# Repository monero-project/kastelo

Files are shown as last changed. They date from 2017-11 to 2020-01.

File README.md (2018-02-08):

# Kastelo
This is the project to create an official Monero Hardware Wallet

[Kastelo logo](https://github.com/monero-project/kastelo/)

1. [Safe, Vault](https://en.wikipedia.org/wiki/Esperanto), a place to store valuables
2. An open hardware Monero wallet

## Are you a tester looking for FW?
Please go to firmware/monezor and read the README there

## Disclaimers
- No hardware available
- Currently in the design and pre-fabrication stage

## Documentation
- Project documentation is being written
- [Moneropedia](https://getmonero.org/knowledge-base/moneropedia/) is recommended for a general introduction to the Monero-verse

## Developers
- Contributing advice is found in CONTRIBUTING.md (please review before submitting a pull request)

### Project Management
Follow the engineering pace of our project at:

[https://taiga.getmonero.org/project/michael-rfc-hwallet-1-implementation/](https://taiga.getmonero.org/project/michael-rfc-hwallet-1-implementation/)

## Support
- IRC: [Freenode](irc://chat.freenode.net/#monero-hardware/)
- [Monero StackExchange](https://monero.stackexchange.com/)
- [Mattermost](https://mattermost.getmonero.org/monero/channels/monerohardware/)

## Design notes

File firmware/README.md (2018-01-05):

# README

## About This Repository

This is a basic firmware project for the Monero HW wallet (JULIAN CANDY EDITION) intended to support firmware development. HW information for the JULIAN CANDY device is in the hardware/monezor folder.

It was established by forking and putting together files from three github repositories:

* libopencm3
* libopencm3-examples
* trezor_mcu

The goal of this blank project is to give other developers a clean start for writing cryptographic functions, or for any kind of playing with JULIAN CANDY device. All kinds of activity is welcome, there is a lot of work to be done!

Note that most of the following instruction assumes a Unix, Linux, or similar OS.

## How To Start?

### Compiling

You have to install the arm cross compiling toolchain, since this is used for compiling the code. This can be done (on debian) by running:

```
$ sudo apt-get install gcc-arm-none-eabi
```

Once this is done, there are two separate things to build: the libopencm3 library and the firmware itself. So at first, go to the libopencm3 folder and build the library by running "make". Then, change directory to to the monezor folder.
Run "make" here as well. This should result in the files named monezor.bin and monezor.elf. Once they are there, you can continue with uploading the binary :)

### USB Vendor and Product ID (user flash boot only)

We have applied for the following VID/PID assignments:

* Bootloader circuits 0x1209/0xB0B0
* Consumer editions 0x1209/0xC0DA
* Developer editions 0x1209/0xD00D
* Microchip editions 0x04D8/0x????

We are provisionally using the FOSS VID/PID values:

* Bootloader circuits 0xF055/0xB0B0
* Consumer editions 0xF055/0xC0DA
* Developer editions 0xF055/0xD00D

We have no plans to purchase our own vendor identifer from usb.org.

### USB Rules

Go to the UDEV rules folder:

```
$ cd /etc/udev/rules.d/
```

Make a new file here:

```
$ sudo nano 99-usbdfu.rules
```

Paste these lines in:

```
# STMicroelectronics STM Device in DFU Mode (and clones)
SUBSYSTEM=="usb", ATTR{idVendor}=="0483", ATTR{idProduct}=="df11", MODE="660", GROUP="plugdev"
SUBSYSTEM=="usb", ATTR{idVendor}=="f055", ATTR{idProduct}=="b0b0", MODE="660", GROUP="plugdev"
SUBSYSTEM=="usb", ATTR{idVendor}=="f055", ATTR{idProduct}=="c0da", MODE="660", GROUP="plugdev"
SUBSYSTEM=="usb", ATTR{idVendor}=="f055", ATTR{idProduct}=="d00d", MODE="660", GROUP="plugdev"
SUBSYSTEM=="usb", ATTR{idVendor}=="1209", ATTR{idProduct}=="b0b0", MODE="660", GROUP="plugdev"
SUBSYSTEM=="usb", ATTR{idVendor}=="1209", ATTR{idProduct}=="c0da", MODE="660", GROUP="plugdev"
SUBSYSTEM=="usb", ATTR{idVendor}=="1209", ATTR{idProduct}=="d00d", MODE="660", GROUP="plugdev"
```

And restart your computer (or try to restart rules by this command):

```
$ sudo udevadm control --reload-rules
$ sudo udevadm trigger --action=change
```

If you later hit some problems with uploading, please check if you have rules recognized.

### Uploading the Binary to the Device

Basically you need couple of things, depending how you want to upload the binary to the device's MCU.

If you choose to upload the binary with a USB cable, it is convenient, but you cannot do stepwise debugging or use breakpoints in code. For more granular (stepwise and breakpoint) debugging, you need to use a dedicated programmer and connect it to the JTAG port of the device (please see PDF schematics in the hardware/monezor/schematics folder) in question.

#### Uploading by USB

For flashing firmware over the USB cable, we are using ST Microelectronic's factory internal bootloader\*. This may not yield a secure boot procedure, but is quite appropriate for the rapid prototyping we're currently working on. Using this bootloader is just fine for now, since it allows to upload and test binaries without a special programmer device.

\* This bootloader cannot be deleted and we are using it because of it allows convenient uploading of binaries, even for those not owning a special programmer.

For carrying out the prescribed upload procedure, install dfu-util (this is a tool for uploading binaries over USB to devices supporting usb-dfu bootloading.)

```
$ sudo apt-get install dfu-util
```

1. Unplug your device
2. There are two jumpers on the board, just next to display. Each of them could be either in the left position (between pins 1 & 2), or the right position (between pins 2 & 3). These jumpers determine in which mode the MCU is bootloading. Put both jumper to the right positions.
3. Connect the device (you should see in dmesg, that you connected STM DFU device, which is what we need, since we are going to flash our binary by using the STM DFU on-chip bootloader.)

Now go to the firmware/monezor folder and type `make program`.
Note: if you unplug and plug in the device now, it will again boot into bootloader mode with the display turned off. So, to see the device working you have to unplug it, move the left jumper to the left position causing the MCU to boot into the binary which we just uploaded, and plug the device in again.

#### Upload by ST-LINK programmer

For flashing the firmware using a ST-LINK programmer, you have to install openocd as well:

http://openocd.org/

Be sure to provide voltage to the board before plugging in the programmer. Connect the programmer to the JTAG port, go to the firmware/monezor folder and type `make flash`.

Note: If the ST-LINK programmer is not plugged into a power supply, it holds the reset pin on the GND by default, leading to a false impression that the MCU seems to be dead :)

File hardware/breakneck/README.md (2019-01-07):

# Hardware Breakneck Design

The Breakneck design includes rich features typical of a developer edition hardware wallet.

[Breakneck schematic print](https://github.com/monero-project/kastelo/raw/master/hardware/breakneck/schematic/breakneck-sch.pdf)

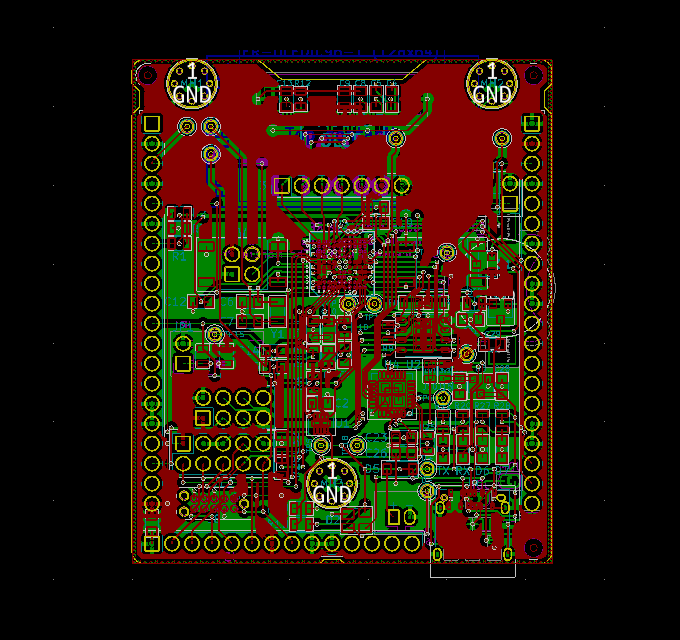
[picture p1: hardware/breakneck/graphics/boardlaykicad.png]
Breakneck CAD layout
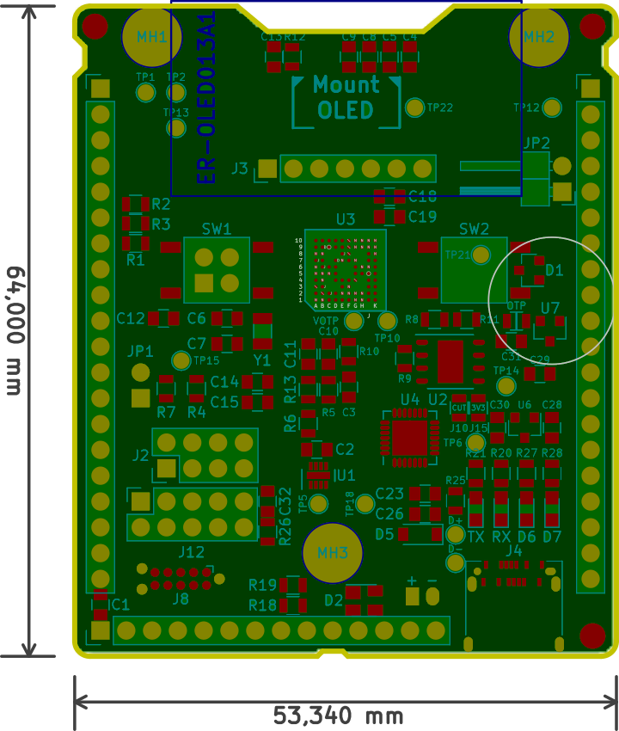
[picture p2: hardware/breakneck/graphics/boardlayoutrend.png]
Breakneck board layout
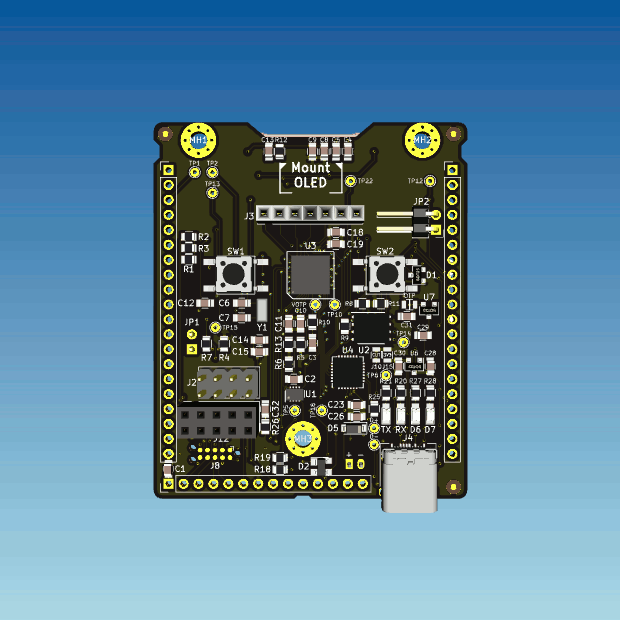
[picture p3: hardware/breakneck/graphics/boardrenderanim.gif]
Breakneck shaded animation
[](https://raw.githubusercontent.com/monero-project/kastelo/master/hardware/breakneck/graphics/boardlaykicad.png)&nbsp;&nbsp;[](https://raw.githubusercontent.com/monero-project/kastelo/master/hardware/breakneck/graphics/boardlayoutrend.png)&nbsp;&nbsp;[](https://raw.githubusercontent.com/monero-project/kastelo/master/hardware/breakneck/graphics/boardrenderanim.gif)

## Getting Started

The Breakneck design consists of several files, some which are not tracked in revision control but are part of [project releases](https://github.com/monero-project/kastelo/releases/).

* breakneck.pro (KiCad project)
* breakneck.sch (KiCad schematic)
* breakneck.kicad_pcb (KiCad layout)
* libraries (KiCad libraries)
* modules (KiCad footprints)

Fabrication subdirectories contain files meant for printing, assembly, and other production work.

* billofmat (Bill of materials generated from the layout)
* fabpanel (Gerber files for printing panelized PCBs)
* fabraster (3D rendition of a single PCB layout)
* fabsingle (Gerber files for printing single PCBs)
* fabvector (Vector files useful for mechanical engineering)

Other subdirectories exist to provide conveniently formatted files generated from source.

* release (Tested distribution release files containing change logs)
* schematic (Copy of breakneck.sch converted to common graphic formats)

A Makefile serves project management tasks allowing for scripting and automation.

* Makefile (A GNU Makefile facilitating command line project tasks)

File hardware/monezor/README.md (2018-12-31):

## Monezor Design Status

This was the monezor hw wallet PCB revision control.

New development of STM32 based designs throughout the project stopped after the Julian Candy released hardware revision 0.2.0.

## Exit Reasoning

STM32 integration stopped as the architecture (at least M3 based MCUs) failed to meet expectations, as well as better architectures with immutable boot and hardware cryptography appeared.

## Maintenance Plan

STM32 design is maintained in the (developer edition) Breakneck codebase, for those who prefer the architecture opposed to the advanced and improved one found in the tip master of revision control.

To find the STM32 based Breakneck codebase, switch to the _revstm_ branch:

```
$ git checkout revstm
$ cd hardware/breakneck
```

## Development Plan

New features are found in the Breakneck master codebase which migrates logic to a new consumer edition codebase as UX and functional testing mandates.

To find the current Breakneck codebase, switch to the _master_ branch:

```
$ git checkout master
$ cd hardware/breakneck
```

## New Architecture

Although nRF52840 is a candidate, the replacement for STM32 parts in new designs is CEC1702.

## Preservation Plan

The STM32 based Monezor codebase is preserved in the _revstm_ branch.

## Glossary

- **Consumer edition:** One of two Monero dedicated hardware wallet editions, integrating a well tested subset of features from the developer edition.
- **Developer edition:** One of two Monero dedicated hardware wallet editions, including all features. For example, the developer edition may contain experimental intrusion detection while the consumer edition may not (unless the features are proven stable and useful.)
- **Monezor:** The model name associated with the consumer edition.
- **Breakneck:** The model name associated with the developer edition.
- **Julian Candy:** A code name corresponding with a range of hardware revisions including 0.2.0.
- **Extra Tabulo:** A code name corresponding with a range of hardware revisions including 0.9.0.

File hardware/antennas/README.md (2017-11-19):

# Hardware Antennas Subdirectory

One paragraph of descriptive text.

## Getting Started

Example text to help understand contents and subdirectories.

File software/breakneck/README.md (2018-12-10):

# Host Software for Breakneck

This area serves software projects for the Breakneck and similar device models. Deliverables run on consumer grade desktop computers and mobile devices. For MCU bound firmware, please navigate to the corresponding parent directory.

## Getting Started

Example text to help understand contents and subdirectories.

---

## Development Platforms

To provide quality sofware while reducing maintenance, abstraction frameworks are used:

* [Electron](https://https://electronjs.org/)
* [React Native](https://facebook.github.io/react-native/)

Electron is used to produce binaries for desktop hosts whereas React Native is used to produce binaries for mobile hosts. A console application serves text based use requirements.

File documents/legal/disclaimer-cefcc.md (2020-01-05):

# CE and FCC mark exception notice

## Evaluation Products not Requiring FCC Equipment Authorisation (FCC Rule 2.803)

FCC NOTICE: This kit is designed to allow:
(1) Product developers to evaluate electronic components, circuitry, or software associated with the kit to determine whether to incorporate such items in a finished product and
(2) Software developers to write software applications for use with the end product. This kit is not a finished product and when assembled may not be resold or otherwise marketed unless all required FCC equipment authorisations are first obtained. Operation is subject to the condition that this product not cause harmful interference to licensed radio stations and that this product accept harmful interference. Unless the assembled kit is designed to operate under part 15, part 18 or part 95 of 47 CFR, Chapter I ("FCC Rules"), the operator of the kit must operate under the authority of an FCC license holder or must secure an experimental authorisation under part 5 of this chapter.

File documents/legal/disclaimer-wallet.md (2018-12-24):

# RFC-HWALLET-1 DEVELOPER EDITION DISCLAIMER 20181200

## 1. STATUS

RFC-HWALLET-1 development team (“HWDT”) is a loose collective of individuals with an aim of developing an Open Source printed circuit board design for a dedicated Monero hardware wallet. There is no centralized authority, entity, or institution that controls, dictates, regulates, or makes decisions for, or on behalf of, any member of the collective. It is not the intent of HWDT to form any partnership, joint venture, agency, employer-employee or fiduciary relationship.

## 2. DELIVERY

HWDT delivers a Development Package (“DP”) that includes evaluation boards, components, and/or documentation to developers (“Users”), who are qualified technicians familiar with handling electrical and mechanical components. Users voluntarily and knowingly assume the risks associated with handling such components, which could potentially lead to shock, fire, serious injury, and/or damage to property. Users undertake to take all necessary measures to minimize these risks. The DP is an unfinished product intended to be used for experimentation in a controlled research and development setting. The DP may not be sold for consumer or commercial use.

## 3. DISCLAIMER

The DP is provided “as is” and any express or implied warranties, including, but not limited to, implied warranties of merchantability, of satisfactory quality, non-infringement of third party rights, and fitness for a particular purpose or use are disclaimed. HWDT makes no representation that DP, does or will not infringe any patent, copyright, trade secret or other proprietary right. Users warrant that they do not act in a consumer capacity.

## 4. LIMITATION OF LIABILITY

HWDT shall have no liability, neither jointly nor severally, for direct, indirect, special, incidental, consequential, exemplary, punitive or other damages of any character including, without limitation, procurement of substitute goods or services, loss of use, data or profits, or business interruption, however caused and on any theory of contract, warranty, tort (including negligence), product liability or otherwise, arising in any way in relation to the DP. Users shall hold HWDT free and harmless from any and all liability, costs, damages, fees and expenses, including claims by third parties.

## 5. SANCTIONS

Users acknowledge that the DP may include technology subject to sanctions, embargoes, or export control regulations and shall undertake to ensure compliance with any applicable laws.

## 6. CUSTOMS

The DP is intended to be used exclusively for testing to find out components’ composition, quality or other characteristics for information, or for industrial or commercial research. Users may be able to import DP free from duty, excise duty and VAT in some countries, but should consult with the appropriate local authorities on how to obtain relief. Normally, Users must completely use up or destroy goods in the course of the testing to qualify for relief.

## 7. EVALUATION TOKENS

Some devices may include evaluation tokens. These tokens exist in a test network (“testnet”), which is separate from the main Monero network and subject to network resets at any time. As such, said tokens do not contain any value. Testnet addresses are identified by an address prefix that start with A, B, or 9.

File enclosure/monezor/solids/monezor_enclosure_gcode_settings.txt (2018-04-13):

;   processName,Medium Res 0.17 
;   applyToModels,monezor_enclosure
;   profileName,Default (modified)
;   profileVersion,2015-05-01 08:00:00
;   baseProfile,
;   printMaterial,
;   printQuality,
;   printExtruders,
;   extruderName,Extruder 1
;   extruderToolheadNumber,0
;   extruderDiameter,0.4
;   extruderAutoWidth,1
;   extruderWidth,0.48
;   extrusionMultiplier,1
;   extruderUseRetract,1
;   extruderRetractionDistance,0.5
;   extruderExtraRestartDistance,0
;   extruderRetractionZLift,0
;   extruderRetractionSpeed,2400
;   extruderUseCoasting,1
;   extruderCoastingDistance,0.2
;   extruderUseWipe,1
;   extruderWipeDistance,2
;   primaryExtruder,0
;   layerHeight,0.17
;   topSolidLayers,6
;   bottomSolidLayers,4
;   perimeterOutlines,2
;   printPerimetersInsideOut,1
;   startPointOption,3
;   startPointOriginX,200
;   startPointOriginY,0
;   sequentialIslands,0
;   spiralVaseMode,0
;   firstLayerHeightPercentage,150
;   firstLayerWidthPercentage,100
;   firstLayerUnderspeed,0.5
;   useRaft,1
;   raftExtruder,0
;   raftTopLayers,3
;   raftBaseLayers,2
;   raftOffset,2
;   raftSeparationDistance,0.18
;   raftTopInfill,100
;   aboveRaftSpeedMultiplier,0.3
;   useSkirt,0
;   skirtExtruder,0
;   skirtLayers,1
;   skirtOutlines,1
;   skirtOffset,1
;   usePrimePillar,0
;   primePillarExtruder,999
;   primePillarWidth,12
;   primePillarLocation,7
;   primePillarSpeedMultiplier,1
;   useOozeShield,0
;   oozeShieldExtruder,999
;   oozeShieldOffset,2
;   oozeShieldOutlines,1
;   oozeShieldSidewallShape,1
;   oozeShieldSidewallAngle,30
;   oozeShieldSpeedMultiplier,1
;   infillExtruder,0
;   internalInfillPattern,Rectilinear
;   externalInfillPattern,Rectilinear
;   infillPercentage,10
;   outlineOverlapPercentage,15
;   infillExtrusionWidthPercentage,125
;   minInfillLength,5
;   infillLayerInterval,1
;   internalInfillAngles,45,-45
;   overlapInternalInfillAngles,0
;   externalInfillAngles,45,-45
;   generateSupport,1
;   supportExtruder,0
;   supportInfillPercentage,30
;   supportExtraInflation,0
;   supportBaseLayers,0
;   denseSupportExtruder,0
;   denseSupportLayers,0
;   denseSupportInfillPercentage,70
;   supportLayerInterval,1
;   supportHorizontalPartOffset,1
;   supportUpperSeparationLayers,2
;   supportLowerSeparationLayers,2
;   supportType,0
;   supportGridSpacing,4
;   maxOverhangAngle,60
;   supportAngles,0
;   temperatureName,Extruder 1 Temperature,Heated Bed
;   temperatureNumber,0,0
;   temperatureSetpointCount,1,1
;   temperatureSetpointLayers,1,1
;   temperatureSetpointTemperatures,200,60
;   temperatureStabilizeAtStartup,1,1
;   temperatureHeatedBed,0,1
;   temperatureRelayBetweenLayers,0,0
;   temperatureRelayBetweenLoops,0,0
;   fanLayers,1,2,3,5
;   fanSpeeds,0,20,40,80
;   blipFanToFullPower,1
;   adjustSpeedForCooling,1
;   minSpeedLayerTime,5
;   minCoolingSpeedSlowdown,20
;   increaseFanForCooling,0
;   minFanLayerTime,45
;   maxCoolingFanSpeed,100
;   increaseFanForBridging,0
;   bridgingFanSpeed,100
;   use5D,1
;   relativeEdistances,0
;   allowEaxisZeroing,1
;   independentExtruderAxes,0
;   includeM10123,0
;   stickySupport,1
;   applyToolheadOffsets,0
;   gcodeXoffset,0
;   gcodeYoffset,0
;   gcodeZoffset,0
;   overrideMachineDefinition,0
;   machineTypeOverride,0
;   strokeXoverride,200
;   strokeYoverride,200
;   strokeZoverride,200
;   originOffsetXoverride,0
;   originOffsetYoverride,0
;   originOffsetZoverride,0
;   homeXdirOverride,-1
;   homeYdirOverride,-1
;   homeZdirOverride,-1
;   flipXoverride,1
;   flipYoverride,-1
;   flipZoverride,1
;   toolheadOffsets,0,0|0,0|0,0|0,0|0,0|0,0
;   overrideFirmwareConfiguration,0
;   firmwareTypeOverride,RepRap (Marlin/Repetier/Sprinter)
;   GPXconfigOverride,r2
;   baudRateOverride,115200
;   overridePrinterModels,0
;   printerModelsOverride
;   startingGcode,;M190 S{print_bed_temperature} 	;Uncomment to add your own bed temperature line,;M109 S{print_temperature} 		;Uncomment to add your own temperature line,G21       			;metric values,G90      			;absolute positioning,M82      			;set extruder to absolute mode,M107      			;start with the fan off,G28 X0 Y0 			;move X/Y to min endstops,G28 Z0     			;move Z to min endstops,G1 Z5.0 F1500			;move the platform down 15mm,G1 Z0			;move extruder to 0,G92 E0                		;zero the extruded length,G1 F900 E20              		;extrude 10mm of feed stock,G92 E0                 		;zero the extruded length again,G1 F{travel_speed},M117 Leave me alone!... 		;Put printing message on LCD screen
;   layerChangeGcode,
;   retractionGcode,
;   toolChangeGcode,
;   endingGcode,;End GCode,M104 S0 		;extruder heater off,M140 S0 		;heated bed heater off (if you have it),M107     		;disable fans,G91       		;relative positioning,G1 E-10 F900		;retract the filament a bit before lifting the nozzle to release some of the pressure,G1 Z+2 E-10 X-20 Y-20 F1500	;move Z up a bit and retract filament even more,G1 X0 Y200  F1500	;move bed to front,M84		;steppers off,G90		;absolute positioning,;{profile_string},M117 Hooooray!!!...	;Put printing message on LCD screen
;   exportFileFormat,gcode
;   celebration,0
;   celebrationSong,Star Wars
;   postProcessing,
;   defaultSpeed,2400
;   outlineUnderspeed,0.75
;   solidInfillUnderspeed,1
;   supportUnderspeed,1
;   rapidXYspeed,9000
;   rapidZspeed,1002
;   minBridgingArea,10
;   bridgingExtraInflation,0
;   bridgingExtrusionMultiplier,0.9
;   bridgingSpeedMultiplier,1
;   useFixedBridgingAngle,0
;   fixedBridgingAngle,0
;   applyBridgingToPerimeters,0
;   filamentDiameters,1.75|1.75|1.75|1.75|1.75|1.75
;   filamentPricesPerKg,36|36|36|36|36|36
;   filamentDensities,1.25|1.25|1.25|1.25|1.25|1.25
;   useMinPrintHeight,0
;   minPrintHeight,0
;   useMaxPrintHeight,0
;   maxPrintHeight,0
;   useDiaphragm,0
;   diaphragmLayerInterval,20
;   robustSlicing,1
;   mergeAllIntoSolid,0
;   onlyRetractWhenCrossingOutline,0
;   retractBetweenLayers,1
;   useRetractionMinTravel,0
;   retractionMinTravel,3
;   retractWhileWiping,0
;   onlyWipeOutlines,1
;   avoidCrossingOutline,0
;   maxMovementDetourFactor,3
;   toolChangeRetractionDistance,0
;   toolChangeExtraRestartDistance,0
;   toolChangeRetractionSpeed,360
;   externalThinWallType,0
;   internalThinWallType,2
;   thinWallAllowedOverlapPercentage,10
;   singleExtrusionMinLength,1
;   singleExtrusionMinPrintingWidthPercentage,50
;   singleExtrusionMaxPrintingWidthPercentage,200
;   singleExtrusionEndpointExtension,0.2
;   horizontalSizeCompensation,0

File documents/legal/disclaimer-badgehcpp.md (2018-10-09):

# HCPP 18 BADGE DISCLAIMER 20180900

## 1. STATUS

The Monero Hardware Team (“MHT”) is a loose collective of individuals that aim to provide hardware at HCPP 18. There is no centralized authority, entity, or institution that controls, dictates, regulates, or makes decisions for, or on behalf of, any member of the collective. It is not the intent of MHT to form any partnership, joint venture, agency, employer-employee or fiduciary relationship.

## 2. DELIVERY

MHT delivers a HCPP 18 Badge (“BADGE”) that is constructed of open electrical components to Users on condition that Users voluntarily and knowingly assume the risks associated with handling such components, which could potentially lead to shock, fire, serious injury, and/or damage to property. Users undertake to take all necessary measures to minimize these risks. The BADGE is an unfinished product to be used for experimentation and does not have any specific intended use case.

## 3. DISCLAIMER

The BADGE is provided “AS IS” and any express or implied warranties, including, but not limited to, implied warranties of merchantability, of satisfactory quality, non-infringement of third party rights, and fitness for a particular purpose or use are disclaimed. MHT makes no representation that BADGE does or will not infringe any patent, copyright, trade secret or other proprietary right.

## 4. LIMITATION OF LIABILITY

MHT shall have no liability, neither jointly nor severally, for direct, indirect, special, incidental, consequential, exemplary, punitive or other damages of any character including, without limitation, procurement of substitute goods or services, loss of use, data or profits, or business interruption, however caused and on any theory of contract, warranty, tort (including negligence), product liability or otherwise, arising in any way in relation to the BADGE. Users shall hold MHT free and harmless from any and all liability, costs, damages, fees and expenses, including claims by third parties.

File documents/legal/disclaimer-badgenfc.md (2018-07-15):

# MONERO DEFCON 26 BADGE DISCLAIMER 20180700

## 1. STATUS

The Monero Village (“MV”) is a loose collective of individuals that aim to represent the Monero Project at DefCon 26. There is no centralized authority, entity, or institution that controls, dictates, regulates, or makes decisions for, or on behalf of, any member of the collective. It is not the intent of MV to form any partnership, joint venture, agency, employer-employee or fiduciary relationship.

## 2. DELIVERY

MV delivers a Monero DefCon Badge (“BADGE”) that is constructed of open electrical components to Users on condition that Users voluntarily and knowingly assume the risks associated with handling such components, which could potentially lead to shock, fire, serious injury, and/or damage to property. Users undertake to take all necessary measures to minimize these risks. The BADGE is an unfinished product to be used for experimentation and does not have any specific intended use case.

## 3. DISCLAIMER

The BADGE is provided “AS IS” and any express or implied warranties, including, but not limited to, implied warranties of merchantability, of satisfactory quality, non-infringement of third party rights, and fitness for a particular purpose or use are disclaimed. MV makes no representation that BADGE does or will not infringe any patent, copyright, trade secret or other proprietary right.

## 4. LIMITATION OF LIABILITY

MV shall have no liability, neither jointly nor severally, for direct, indirect, special, incidental, consequential, exemplary, punitive or other damages of any character including, without limitation, procurement of substitute goods or services, loss of use, data or profits, or business interruption, however caused and on any theory of contract, warranty, tort (including negligence), product liability or otherwise, arising in any way in relation to the BADGE. Users shall hold MV free and harmless from any and all liability, costs, damages, fees and expenses, including claims by third parties.

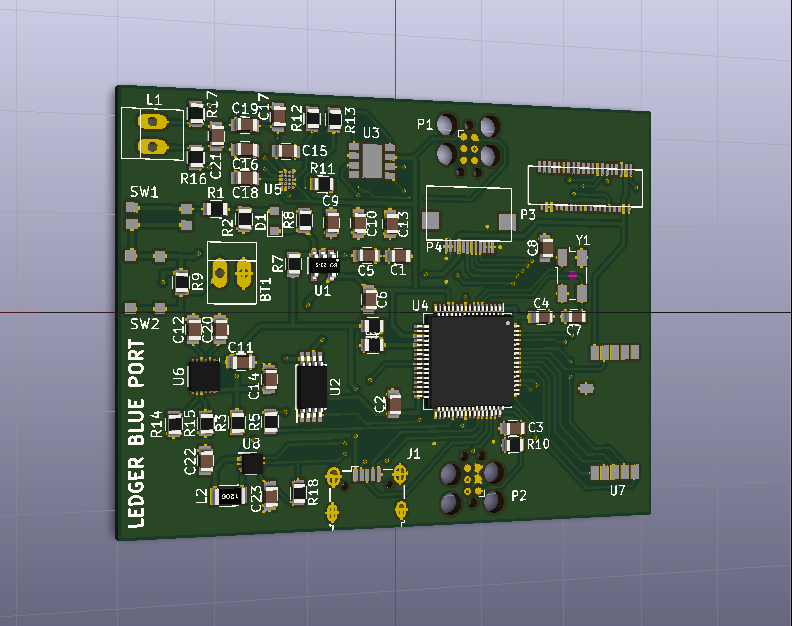
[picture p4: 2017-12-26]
hardware/cloneledg/ledgblue/fabraster/ledgbluerendition.png

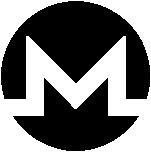
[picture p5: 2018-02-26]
hardware/breakneck/graphics/monerochromcopper.png

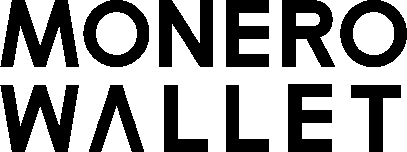
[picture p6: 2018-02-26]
hardware/breakneck/graphics/monerochromtext.png

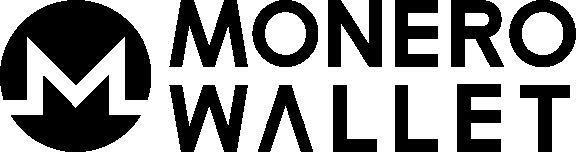
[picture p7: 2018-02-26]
hardware/breakneck/graphics/monerofullchrome.png

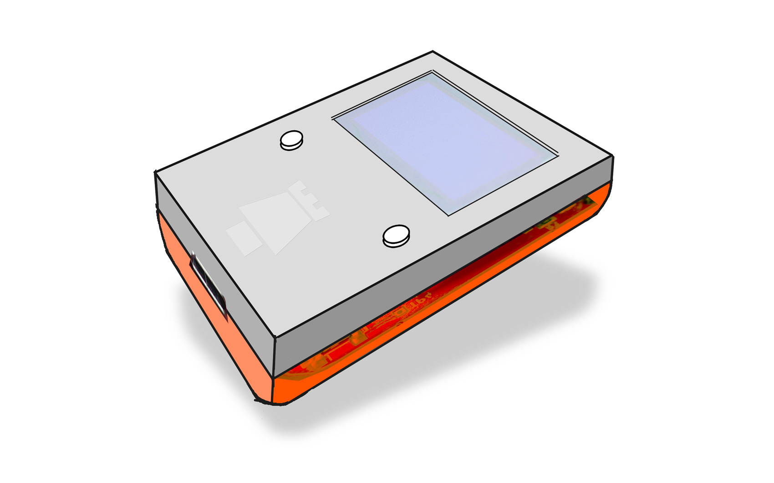
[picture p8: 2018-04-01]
enclosure/monezor/concepts/lowprotwopiece.jpeg

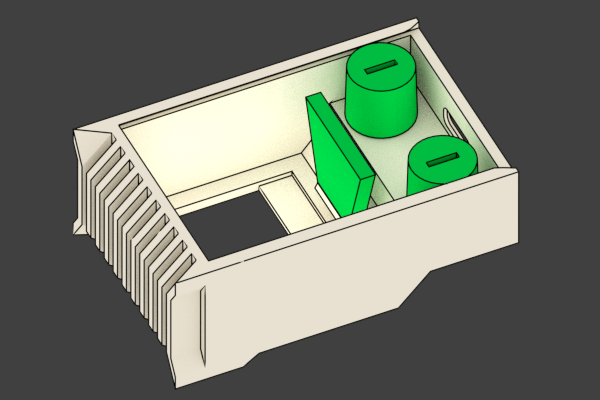
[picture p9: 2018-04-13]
enclosure/monezor/solids/monezor_enclosure_support.png

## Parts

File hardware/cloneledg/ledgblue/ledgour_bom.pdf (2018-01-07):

Ledgour BoM Updated 2018-01-07

Name | Package | Designation | Qty | Link | Alternative link
C1,C2,C3,C4,C9,C13 | C_0805 | 0.1uF | 6 | https //www.arrow.com/en/products/vj0805y104jxxcw1bc/vishay
C5,C6,C22,C23 | C_0805 | 1uF | 4 | https //www.arrow.com/en/products/vj0805y105jxqtw1bc/vishay
C7,C8 | C_0805 | 20pF | 2 | https //www.arrow.com/en/products/nmc0805npo200j50trpf/nic-components
C10,C14 | C_0805 | 4.7uF | 2 | https //www.arrow.com/en/products/vj0805v475zxqtw1bc/vishay
C11,C12,C20 | C_0805 | 2.2uF | 3 | https //www.arrow.com/en/products/vj0805g225kxqtw1bc/vishay
C15 | C_0805 | 0.015uF | 1 | https //www.arrow.com/en/products/cl21b153kbannnc/samsung-electro-mechanics
C16,C17 | C_0805 | 27pF | 2 | https //www.arrow.com/en/products/cl21c270jbannnc/samsung-electro-mechanics
C18,C19 | C_0805 | 180pF | 2 | https //www.arrow.com/en/products/cl21c181jbannnd/samsung-electro-mechanics
C21 | C_0805 | 39pF | 1 | https //www.arrow.com/en/products/cl21c390jbannnc/samsung-electro-mechanics
R1,R2,R14 | R_0805 | 10k | 3 | https //www.arrow.com/en/products/crcw080510k0jnea/vishay
R3,R4,R5,R6 | R_0805 | 1.2k | 4 | https //www.arrow.com/en/products/crcw08051k20fkea/vishay
R7 | R_0805 | 680k | 1 | https //www.arrow.com/en/products/crcw0805680kfkea/vishay
R8 | R_0805 | 1M | 1 | https //www.arrow.com/en/products/crcw08051m00jneahp/vishay
R9,R12,R13,R16,R17 | R_0805 | 0 | 5 | https //www.arrow.com/en/products/rca08050000zsea/vishay
R10,R11 | R_0805 | 100k | 2 | https //www.arrow.com/en/products/crcw0805100kfkeb/vishay
R15 | R_0805 | 1k | 1 | https //www.arrow.com/en/products/crcw08051k00jnta/vishay
R18 | R_0805 | 10 | 1 | https //www.arrow.com/en/products/crcw080510r0jnea/vishay
BT1 | PINHEAD1-2 | Battery | 1 | https //www.arrow.com/en/products/0901200778/molex
L1 | PINHEAD1-2 | Antenna | 1 | https //www.arrow.com/en/products/0901200778/molex
L2 | L_1206 | 10uH | 1 | https //www.arrow.com/en/products/nlcv32t-100k-pfr/tdk
D1 | D_0805 | D_Schottky | 1 | https //www.arrow.com/en/products/sd0805s020s0r5/avx
SW1 | wurth436353045816 | WURTH 436353045816 1 | http //uk.farnell.com/wurth-elektronik/436353045816/switch-160gf-side-wte-j-bend-boss/dp/1868021 | https //www.digikey.com/product-detail/en/wurth-electronics-inc/436353045816/732-7062-1-ND/5225510
SW2 | multicompMCFTE-3C-V | SW-PB | 1 | http //uk.farnell.com/multicomp/mcfte-3c-v/switch-micro-detect-smd/dp/1316985
U1 | SOT-23-5 | LD39020 | 1 | https //www.arrow.com/en/products/ld39020adm30r/stmicroelectronics
U2 | TSSOP-8_4.4x3mm_Pitch0.65mm STMPS2151TTR | 1 | https //www.arrow.com/en/products/stmps2151ttr/stmicroelectronics | https //www.mouser.de/ProductDetail/STMicroelectronics/STMPS2151TTR/?qs qolwYojYp3TtdEE8TCWfkg
U3 | WLCSP | ST31G480 | 1 | N/A to due NDA
U4 | LQFP-64_10x10mm_P tch0.5mm | STM32L476RCT6 | 1 | https //www.arrow.com/en/products/stm32l476rct6/stmicroelectronics
U5 | amsAS3921 | AMS_AS3921 | 1 | https //www.arrow.com/en/products/as3921-bwlt/ams-ag | https //www.mouser.de/ProductDetail/ams/AS3921-BWLM/?qs 16w8nSHsg3vn3%252bCT5rH3bA
U6 | DFN-12-1EP_3x3mm_Pitch0.45mm STNS01PUR | 1 | https //www.arrow.com/en/products/stns01pur/stmicroelectronics
U7 | STSPBTLE-RF | SPBTLE-RF | 1 | https //www.arrow.com/en/products/spbtle-rf/stmicroelectronics | https //www.mouser.de/ProductDetail/STMicroelectronics/SPBTLE-RF0/?qs Mv7BduZupUjx1Mbf4ryoAA%3d%3d
U8 | DFN-6-1EP_2x2mm_Pitch0.5mm | STLA02PUR | 1 | https //www.arrow.com/en/products/stla02pur/stmicroelectronics | https //www.mouser.de/ProductDetail/STMicroelectronics/STLA02PUR/?qs L6eUzyzWLAtrJwKaBBv23Q
Y1 | 4pin_5.0x3.2mm | Abracon_ABM3B_8MHz 1 | https //www.arrow.com/en/products/abm3b-8.000mhz-b2-t/abracon
P1,P2 | Tag Connect TC2030-IDC | Tag Connect TC2030-IDC 2 | http //www.tag-connect.com/TC2030-IDC
P3 | hiroseFH23-39S | YL035MY2 | 1 | https //www.mouser.de/ProductDetail/?qs 0N%252bVULUZFj%2fgb7SvV3hxJA
P4 | wurth687-112-149-022 | YL035MY2_TS_WURTH 1 | https //www.mouser.de/ProductDetail/Wurth-Electronics/687112149022/?qs a9WhcLg8qCybEd8lzi%2fupw
J1 | USB_Micro-B | Wuerth-629105150521 | 1 | https //www.mouser.de/productdetail/wurth-electronics/629105150521?qs sGAEp MZZMulM8LPOQ%252byk2Wnkghg7F8rzYbeZ9K0ijhE7azhp8rv2w

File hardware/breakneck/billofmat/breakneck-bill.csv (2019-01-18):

ID | Reference | Footprint | Quantity | Value | Manufacturer | Datasheet
1 | BT1 | Keystone_3000_1x12mm-CoinCell | 1 | Battery_Cell | Keystone Electronics Corporation | https://www.keyelco.com/product.cfm/product_id/777/
2 | C1,C2,C8,C11,C15,C17,C19,C21,C22,C23,C25,C26 | C_0805 | 12 | 100nF | Yageo Corporation | http://www.yageo.com/documents/recent/UPY-GPHC_Y5V_6.3V-to-50V_8.pdf
3 | C3,C14 | C_0805 | 2 | 470nF | Yageo Corporation | http://www.yageo.com/documents/recent/UPY-GPHC_Y5V_6.3V-to-50V_8.pdf
4 | C4,C5,C9,C10,C12,C16,C18,C28,C29,C30,C31,C32 | C_0805 | 12 | 1uF | Yageo Corporation | http://www.yageo.com/documents/recent/UPY-GPHC_Y5V_6.3V-to-50V_8.pdf
5 | C6,C7 | C_0805 | 2 | 15pF | Yageo Corporation | http://www.yageo.com/documents/recent/UPY-GPHC_Y5V_6.3V-to-50V_8.pdf
6 | C13,C20,C24,C27 | C_0805 | 4 | 2.2uF | Yageo Corporation | http://www.yageo.com/documents/recent/UPY-GPHC_Y5V_6.3V-to-50V_8.pdf
7 | D1 | SOT-23 | 1 | BAT54C | Vishay Intertechnology, Incorporated | http://www.vishay.com/docs/85508/bat54.pdf
8 | D2 | SOT-143 | 1 | SP0503BAHTG | Littelfuse Incorporated | http://www.littelfuse.com/~/media/files/littelfuse/technical%20resources/documents/data%20sheets/sp05xxba.pdf
9 | D3,D4,D6,D7 | LED_0805 | 4 | LED | Osram Opto Semiconductors Incorporated | https://dammedia.osram.info/media/resource/hires/osram-dam-2493936/LG%20R971.pdf
10 | D5 | D_SOD-123 | 1 | D_PMEG | Nexperia B.V. | https://assets.nexperia.com/documents/data-sheet/PMEG3010EGW.pdf
11 | DS1 | Eastrising_ER-CON30HT-1_01x30_P0.50mm | 1 | ER-CON30 | EastRising Technology Corporation, Limited | https://www.buydisplay.com/download/connector/ER-CON30HT-1.pdf
12 | DS2 | Eastrising_ER-CON24HT-1_01x24_P0.50mm | 1 | ER-CON24 | EastRising Technology Corporation, Limited | https://www.buydisplay.com/download/connector/ER-CON24HT-1.pdf
13 | J1 | Pin_Header_Straight_1x20_Pitch2.54mm | 1 | CONN_WEST | Sullins Connector Solutions | https://suddendocs.samtec.com/catalog_english/tsw_th.pdf
14 | J2 | Pin_Header_Straight_2x04_Pitch2.54mm | 1 | CONN_DEDI | Sullins Connector Solutions | https://suddendocs.samtec.com/catalog_english/tsw_th.pdf
15 | J3 | Socket_Strip_Straight_1x07_Pitch2.54mm | 1 | CONN_OLED | Sullins Connector Solutions | http://www.sullinscorp.com/product/?pn=PPTC071LFBN-RC
16 | J4 | USB_C_Receptacle_Amphenol_12401610E4-2A | 1 | USB_C_Receptacle | Amphenol Corporation | https://cdn.amphenol-icc.com/media/wysiwyg/files/drawing/c12401610_c.pdf
16 | J5 | Pin_Header_Straight_1x14_Pitch2.54mm | 1 | CONN_SOUTH | Sullins Connector Solutions | https://suddendocs.samtec.com/catalog_english/tsw_th.pdf
18 | J6 | Pin_Header_Straight_1x20_Pitch2.54mm | 1 | CONN_EAST | Sullins Connector Solutions | https://suddendocs.samtec.com/catalog_english/tsw_th.pdf
19 | J7 | 10120045-401LF | 1 | Badgebus | Amphenol Corporation | https://cdn.amphenol-icc.com/media/wysiwyg/files/documentation/datasheet/boardwiretoboard/bwb_rotaconnect_rotatable_btb.pdf
20 | J12 | Socket_Strip_Angled_2x05_Pitch2.54mm | 1 | CONN_JTAG_6P | Samtec Incorporated | https://suddendocs.samtec.com/catalog_english/ssq_th.pdf
21 | J13 | microSD_Card_Receptacle_Hirose_DM3AT-SF-PEJM5 | 1 | Micro_SD_Card_Det | Hirose Electric Corporation, LTD | https://www.hirose.com/product/en/download_file/key_name/DM3AT-SF-PEJM5/category/Catalog/doc_file_id/49662/
22 | J16 | JST_PH_B2B-PH-K_02x2.00mm_Straight | 1 | CONN_JST | J.S.T. Manufacturing Corporation, Limited | http://www.jst-mfg.com/product/pdf/eng/ePH.pdf
23 | JP1,JP2 | Pin_Header_Angled_1x02_Pitch2.54mm | 2 | Jumper | Sullins Connector Solutions | https://suddendocs.samtec.com/catalog_english/tsw_th.pdf
24 | R1,R7 | R_0805 | 2 | 0 | Stackpole Electronics Incorporated | https://www.seielect.com/Catalog/SEI-RMCF_RMCP.pdf
25 | R2 | R_0805 | 1 | 12K | Stackpole Electronics Incorporated | https://www.seielect.com/Catalog/SEI-RMCF_RMCP.pdf
26 | R3 | R_0805 | 1 | 22K | Stackpole Electronics Incorporated | https://www.seielect.com/Catalog/SEI-RMCF_RMCP.pdf
27 | R4,R29 | R_0805 | 2 | 10K | Stackpole Electronics Incorporated | https://www.seielect.com/Catalog/SEI-RMCF_RMCP.pdf
28 | R5,R6 | R_0805 | 2 | 3.9K | Stackpole Electronics Incorporated | https://www.seielect.com/Catalog/SEI-RMCF_RMCP.pdf
29 | R8,R9,R11,R26 | R_0805 | 4 | 100K | Stackpole Electronics Incorporated | https://www.seielect.com/Catalog/SEI-RMCF_RMCP.pdf
30 | R10 | R_0805 | 1 | 10 | Stackpole Electronics Incorporated | https://www.seielect.com/Catalog/SEI-RMCF_RMCP.pdf
31 | R12,R14 | R_0805 | 2 | 390K | Stackpole Electronics Incorporated | https://www.seielect.com/Catalog/SEI-RMCF_RMCP.pdf
32 | R13 | R_0805 | 1 | 100 | Stackpole Electronics Incorporated | https://www.seielect.com/Catalog/SEI-RMCF_RMCP.pdf
33 | R15 | R_0805 | 1 | 1.5K | Stackpole Electronics Incorporated | https://www.seielect.com/Catalog/SEI-RMCF_RMCP.pdf
34 | R16,R17 | R_0805 | 2 | 2.4K | Stackpole Electronics Incorporated | https://www.seielect.com/Catalog/SEI-RMCF_RMCP.pdf
35 | R18 | R_0805 | 1 | 22.1K | Stackpole Electronics Incorporated | https://www.seielect.com/Catalog/SEI-RMCF_RMCP.pdf
36 | R19 | R_0805 | 1 | 47.5K | Stackpole Electronics Incorporated | https://www.seielect.com/Catalog/SEI-RMCF_RMCP.pdf
37 | R27,R28 | R_0805 | 2 | 150 | Stackpole Electronics Incorporated | https://www.seielect.com/Catalog/SEI-RMCF_RMCP.pdf
38 | R20,R21 | R_0805 | 2 | 220 | Stackpole Electronics Incorporated | https://www.seielect.com/Catalog/SEI-RMCF_RMCP.pdf
39 | R22,R25 | R_0805 | 2 | 1K | Stackpole Electronics Incorporated | https://www.seielect.com/Catalog/SEI-RMCF_RMCP.pdf
40 | R23 | R_0805 | 1 | 130K | Stackpole Electronics Incorporated | https://www.seielect.com/Catalog/SEI-RMCF_RMCP.pdf
41 | R24 | R_0805 | 1 | 220K | Stackpole Electronics Incorporated | https://www.seielect.com/Catalog/SEI-RMCF_RMCP.pdf
42 | SW1,SW2 | SW_SPST_K21102SP | 2 | SW_SPST | Korean Hroparts Electronics Corporation, LTD | https://datasheet.lcsc.com/szlcsc/Korean-Hroparts-Elec-K2-1102SP-C4SC-04_C127509.pdf
43 | SW3 | SW_SPST_ESE11MV1 | 1 | SW_SPST | Panasonic Electronic Components | https://industrial.panasonic.com/cdbs/www-data/pdf/ATB0000/ATB0000C14.pdf
44 | SW4 | SW_SPDT_CLSB-12A | 1 | SW_SPDT | Nidec Copal Electronics Incorporated | https://www.nidec-copal-electronics.com/e/catalog/switch/cl-sb.pdf
45 | TP1-TP22 | TestPoint_THTPad_D1.5mm_Drill0.7mm | 22 | Testpoints (various)
46 | U1 | DFN-8-1EP_2x3mm_Pitch0.5mm | 1 | ATECC508A | Atmel Corporation | http://ww1.microchip.com/downloads/en/DeviceDoc/20005927A.pdf
47 | U2 | DFN-S-8-1EP_6x5mm_Pitch1.27mm | 1 | SST26VF064B | Microchip Technology Incorporated | https://www.microchip.com/downloads/en/DeviceDoc/00002207C.pdf
48 | U3 | WFBGACEC1702 | 1 | CEC1702 | Microchip Technology Incorporated | https://www.microchip.com/downloads/en/DeviceDoc/00002207C.pdf
49 | U4 | QFN-28-1EP_5x5mm_Pitch0.5mm | 1 | CP2102N | Silicon Laboratories | https://www.silabs.com/documents/public/data-sheets/cp2102n-datasheet.pdf
50 | U5 | SOT-353_SC-70-5 | 1 | MIC5377YC5 | Microchip Technology Incorporated | https://www.microchip.com/downloads/en/DeviceDoc/MIC5376-7-8-High-Performance-Low-Dropout-150mA-LDO-DS20006080A.pdf
51 | U6 | SOT-23 | 1 | LN6206P33M | Shanghai Nanlin Electronics | http://www.natlinear.com/uploadfiles/2014/LN/LN6206_E.pdf
52 | U7 | SOT-23 | 1 | LN6206P15M | Shanghai Nanlin Electronics | http://www.natlinear.com/uploadfiles/2014/LN/LN6206_E.pdf
53 | X1 | Badgelife-Shitty-2x2 | 1 | Badgelife_shitty | Sullins Connector Solutions | https://www.sullinscorp.com/product/?pn=PPTC022LFBN-RC
54 | Y1 | Crystal_SMD_3215-2Pin_3.2x1.5mm | 1 | Crystal | Seiko Epson Corporation | https://support.epson.biz/td/api/doc_check.php?dl=brief_FC-135R_en.pdf
55 | Z1 | Potting_Compound | 1 | RTV_103 | MG Chemicals | https://www.mgchemicals.com/products/rtv-silicones/adhesives-/-sealants/rtv103/
56 | Z2 | Conformal_Coating | 1 | Sylgard_184 | Dow Chemical | https://consumer.dow.com/content/dam/dcc/documents/en-us/productdatasheet/11/11-31/11-3184-sylgard-184-elastomer.pdf

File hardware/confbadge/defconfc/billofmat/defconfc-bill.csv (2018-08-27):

ID | Description | Qty | Reference | Manufacturer | Model | Package | Value | Vendor primary | Vendor secondary | Datasheet
1 | Generic resistor | 4 | R1,R3,R5,R7 | Yageo | AC0805 | 0805 | 22 | https://www.arrow.com/products/ac0805fr-0722rl/yageo/ | https://www.digikey.com/product-detail/en/yageo/RC0805FR-0722RL/311-22.0CRTR-ND/ | http://www.yageo.com/NewPortal/yageodocoutput?fileName=/pdf/R-Chip/PYu-AC_51_RoHS_L_6.pdf
2 | Orange coloured LED | 16 | D1-D16 | Dialight | 598-8230 | 1206 | 607nm | https://www.arrow.com/products/598-8230-107f/dialight/ | https://www.digikey.com/product-detail/en/dialight/5988230107F/350-2049-1-ND/ | http://www.dialightsignalsandcomponents.com/Assets/Brochures_And_Catalogs/Indication/CBI_SMD_new/Dialight_CBI_data_598-1206_Apr2018.pdf
3 | Dynamic NFC tag IC with EEPROM | 2 | U1,U2 | ST Microelectronics | M24SR02-Y | SOIC-8 | EEPROM | https://www.arrow.com/products/m24sr02-ymn6t2/stmicroelectronics/ | https://www.digikey.com/product-detail/en/stmicroelectronics/M24SR02-YMN6T-2/497-14353-2-ND/ | http://www.st.com/en/nfc/m24sr-series-dynamic-nfc-tags.html
4 | 8-bit AVR 8 MHz microcontroller | 1 | U3 | Atmel | ATTINY13A-SSU | SOIC-8 | MCU | https://www.arrow.com/products/attiny13a-ssur/microchip-technology/ | https://www.digikey.com/product-detail/en/microchip-technology/ATTINY13A-SSUR/ATTINY13A-SSURTR-ND/ | https://www.microchip.com/wwwproducts/ATtiny13A/
5 | Momentary tactile button switch | 3 | SW1-SW3 | C&K | PTS645S-SMTR92 | 6mmX4.5mm | SPST | https://www.arrow.com/products/pts645sk95smtr92lfs/ck/ | https://www.digikey.com/product-detail/en/c-k/PTS645SM43SMTR92-LFS/CKN9112TR-ND/ | https://www.ckswitches.com/media/1471/pts645.pdf
6 | Two position sliding switch | 1 | SW4 | C&K | JS102011SAQN | 9mmX3.5mm | SPDT | https://www.arrow.com/products/js102011saqn/ck/ | https://www.digikey.com/product-detail/en/c-k/JS102011SAQN/401-1999-2-ND/ | https://www.ckswitches.com/media/1422/js.pdf
7 | 20mm coincell battery clip | 1 | BT1 | Keystone | 3034 | 24mmX16mm | 2032-Cell | https://www.arrow.com/products/3034tr/keystone-electronics/ | https://www.digikey.com/product-detail/en/keystone-electronics/3034/36-3034-ND/ | http://keyelco.com/userAssets/file/M65p9.pdf

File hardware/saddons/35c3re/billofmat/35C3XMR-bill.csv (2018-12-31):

ID | Reference | Footprint | Quantity | Value | Manufacturer | Datasheet | Supplier
1 | C1 | 0805 | 1 | 4,7uF | Yageo Corporation | http://www.yageo.com/documents/recent/UPY-GPHC_X5R_4V-to-50V_25.pdf | https://www.arrow.com/en/products/cc0805kkx5r6bb475/yageo/
2 | C2 | 0805 | 1 | ,01uF | Kemet Electronics Corporation | https://content.kemet.com/datasheets/KEM_C1002_X7R_SMD.pdf | https://www.arrow.com/en/products/c0805c103m5ractu/kemet-corporation/
3 | R1 | 0805 | 1 | 10K | Stackpole Electronics Incorporated | https://www.seielect.com/Catalog/SEI-RMCF_RMCP.pdf | https://www.arrow.com/en/products/rmcf0805ft10k0/stackpole-electronics/
4 | R2 | 0805 | 1 | 100K | Stackpole Electronics Incorporated | https://www.seielect.com/Catalog/SEI-RMCF_RMCP.pdf | https://www.arrow.com/en/products/rmcf0805ft100k/stackpole-electronics/
5 | NC | 0805 | 1 | Jumper | Yageo Corporation | http://www.yageo.com/documents/recent/PYu-RC0805_51_RoHS_L_v5.pdf | https://www.arrow.com/en/products/rc0805fr-070rl/yageo/
6 | D1,D3,D5,D7,D8,D9,D11,D13,D15,D17,D19,D21,D23,D25,D27,D29,D31,D33,D35,D37,D39,D41,D43,D45,D47,D49,D51,D53,D55 | 1206 | 28 | LEDColorA | Dialight PLC | http://www.dialightsignalsandcomponents.com/Assets/Brochures_And_Catalogs/Indication/CBI_SMD_new/Dialight_CBI_data_599-1206_Apr2018.pdf | https://www.arrow.com/en/products/5990240007f/dialight/
7 | D2,D4,D6,D8,D10,D12,D14,D16,D18,D20,D22,D24,D26,D28,D30,D32,D34,D36,D38,D40,D42,D44,D46,D48,D50,D52,D54,D56 | 1206 | 28 | LEDColorB | Dialight PLC | http://www.dialightsignalsandcomponents.com/Assets/Brochures_And_Catalogs/Indication/CBI_SMD_new/Dialight_CBI_data_599-1206_Apr2018.pdf | https://www.arrow.com/en/products/5990291007f/dialight/
8 | U1 | SOIC8 | 1 | TLC555 | Texas Instruments Incorporated | https://www.ti.com/lit/gpn/tlc555 | https://www.arrow.com/en/products/tlc555idr/texas-instruments/
9 | U2 | MicroPak6 | 1 | NC7SZ04L6X | ON Semiconductor Corporation | https://www.onsemi.com/pub/Collateral/NC7SZ04-D.PDF | https://www.arrow.com/en/products/nc7sz04l6x/on-semiconductor/
10 | SAO1 | PinHeaderSMD2x2 | 1 | Shittyconn | Samtec Incorporated | https://suddendocs.samtec.com/catalog_english/tsm.pdf | https://www.arrow.com/en/products/tsm-102-01-t-dv/samtec/
11 | BT1,BT2 | Keystone3008 | 2 | Batteryholder | Keystone Electronics Corporation | https://www.keyelco.com/product.cfm/product_id/3948/ | https://www.arrow.com/en/products/3008tr/keystone-electronics/
12 | CR2450-A | Consumable | 1 | Energy Supply | Panasonic Corporation | N/A | https://www.cheap-batteries.com/CR2450.html
13 | CR2450-B | Consumable | 1 | Energy Supply | Varta AG | N/A | https://www.thebatterysupplier.com/products/cr2450-lithium-button-cell-batteries-pack-of-25.html

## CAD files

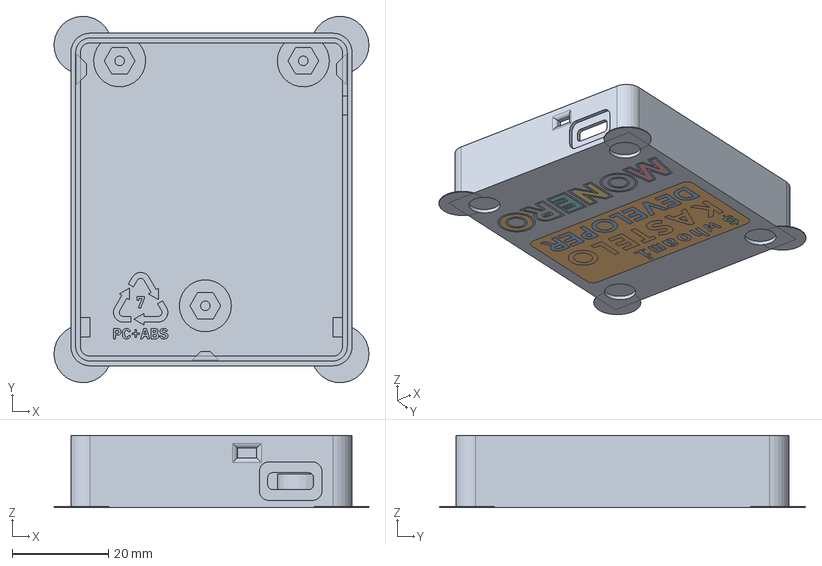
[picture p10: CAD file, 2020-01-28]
enclosure/breakneck/bneckfdmpla.fcstd
65.3 x 76.0 x 15.0 mm
Bodybox
Bodyetik
BodyM1
BodyO1
BodyN1
BodyE1
BodyR1
BodyO2
Textwhotrude
Textkastrude
Textdevtrude
Textquestrude
BodyMa
BodyOa
BodyNa
BodyEa
BodyRa
BodyOb

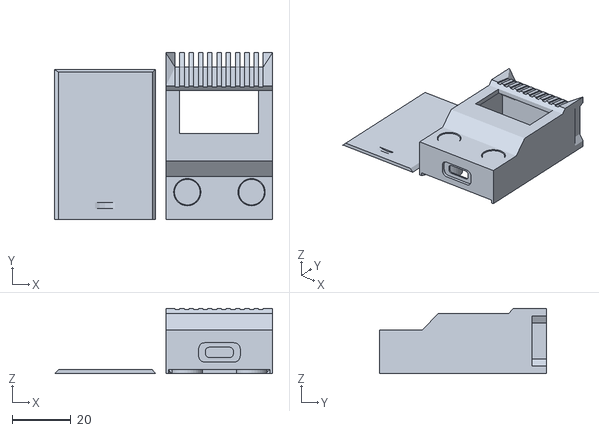
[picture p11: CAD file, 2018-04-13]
enclosure/monezor/solids/monezor_enclosure.stl
74.1 x 56.6 x 22.1

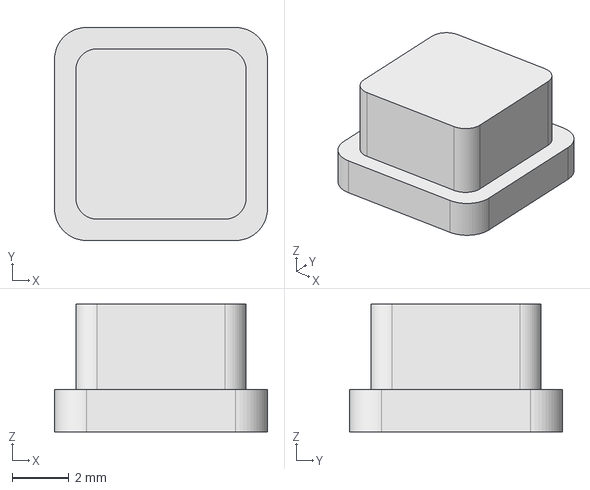
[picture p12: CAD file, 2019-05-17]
enclosure/breakneck/bneckbuttons.fcstd
7.50 x 7.50 x 4.50 mm

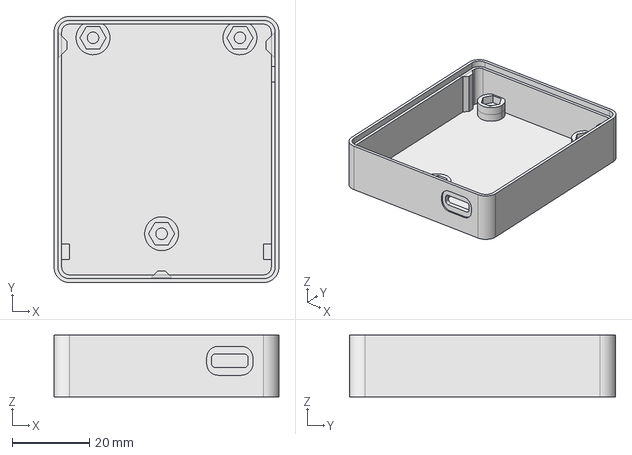
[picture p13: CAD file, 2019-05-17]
enclosure/breakneck/bneckmoldpc.fcstd
58.3 x 69.0 x 16.0 mm

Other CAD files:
hardware/cloneledg/ledgblue/footprints_gbrdxf/u2_ST31G480.dxf
hardware/cloneledg/ledgblue/footprints_gbrdxf/s2_multicompMCFTE-3C-V.dxf
hardware/cloneledg/ledgblue/footprints_gbrdxf/u4_STSPBTLE-RF.dxf
hardware/cloneledg/ledgblue/footprints_gbrdxf/p2_wurth687-112-149-022.dxf
hardware/cloneledg/ledgblue/footprints_gbrdxf/s1_wurth436353045816.dxf
hardware/cloneledg/ledgblue/footprints_gbrdxf/u8_amsAS3921.dxf
hardware/cloneledg/ledgblue/footprints_gbrdxf/p1_hiroseFH23-39S-0.3SHW.dxf
enclosure/monezor/solids/monezor_enclosure.blend

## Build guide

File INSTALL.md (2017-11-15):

To install KiCad
----------------
Please do this.

To install firmware build tools
-------------------------------
Do this, then that, then you're done.

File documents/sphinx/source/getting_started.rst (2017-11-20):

Getting started
===============

Nulla ultricies nulla vitae nibh tincidunt convallis quis eu sem. Vivamus id dictum turpis, vel elementum lacus. Praesent vitae ex ac nunc porttitor volutpat vel id urna. Sed mattis, sem vel posuere tempus, sem nulla laoreet ex, ornare vehicula libero lectus et neque. Fusce posuere eu ex non aliquet. Interdum et malesuada fames ac ante ipsum primis in faucibus. Sed egestas, nibh sit amet tempor porta, ex augue mollis tellus, vel fermentum eros magna nec lacus. Vivamus maximus urna finibus mauris venenatis sollicitudin. Ut non leo nisl.

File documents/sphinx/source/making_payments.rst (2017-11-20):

Making payments
===============

Nunc gravida purus arcu, ut faucibus felis facilisis at. Nam elementum vitae ipsum sit amet congue. Vivamus molestie, urna eget vulputate finibus, neque ligula tempor nibh, non commodo magna purus in lacus. Suspendisse potenti. In rhoncus ultricies nunc et efficitur. Mauris vulputate pretium consequat. Vestibulum dictum mauris vel odio consequat, a semper ipsum consectetur. Curabitur sed dolor turpis. Maecenas malesuada diam ac ligula sollicitudin, vel commodo augue ultrices. Nam convallis lorem at pulvinar tempus. Fusce vitae elit viverra, finibus augue sed, scelerisque lacus. Maecenas libero augue, pellentesque nec feugiat vitae, lobortis ut mi. Vestibulum aliquet mattis ligula, a ultrices lacus rhoncus nec. Donec eget sapien ut augue viverra facilisis quis vel augue. Integer in turpis non tellus scelerisque dictum.

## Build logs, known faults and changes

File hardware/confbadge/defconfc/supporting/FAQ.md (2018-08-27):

Frequently Asked Questions (and Answers)
The other side includes disclaimer text
---------------------------------------

Q: How can I contribute?
A1: Please find a process for two or three colour PCB silkscreening.
A2: Please make 1.6mm PCB compatible 3D (FDM or SLA) structures.
A3: Send pull requests (PR) to github.com/monero-project/kastelo/
A4: Or write to Monero Hardware <hardware@getmonero.org>

Q: Can I DIY make my own badge?
A: Yes, everything needed to hack, analyse, disassemble, create, recreate, or modify is provided (including a license to do so.)

Q: Which license applies?
A: The CERN OSH license for hardware, and the 3-Clause BSD license for firmware, documentation, and online services.

Q: Is the badge Opensource?
A: Yes, excercise your freedom by downloading the schematic, netlist, layout, bill of materials, gerber archive, firmware, work history, and more.

Q: Has anything failed?
A: Yes, we tried multiple silkscreen graphics but partially failed.

Q: How can the NFC storage be accessed?
A1: Use a phone with a NFC application such as NFC Tools.
A2: You can also tap the EEPROM IC legs and hack over I2C.

Q: What type of NFC is supported?
A1: The badge is a NFC Forum Type 4 Tag.
A2: The chosen ICs support ISO/IEC 14443 Type A.
A3: The same RF is used as MIFARE, passports, and 13.56 MHz RFID devices.

Q: Does the badge have a website?
A: Yes, temporarily at kastelo.org/specs/

Q: What is the purpose of buttons SW1 and SW2?
A: Defense against opportunistic data theft.
N: Be careful of butt surfing a needle sized rogue antenna.

Q: Does the badge have family?
A: Yes, a cousin badge will appear at <to-be-announced> in <secret-place>.

Q: Does the badge entitle entrace to a party or village?
A: No, this badge does not entitle entrance to anything.

Q: Can the badge be used for other access control?
A: Only if you hack it first.

Q: May I hack my badge?
A: The badge is unhackable.

Q: Is the badge project sponsored?
A: No, the author paid all costs in cash up front.

Q: How complex is the budget.
A: Very complex, unfortunately.

Q: Can I haz Alien Boss design files?
A: Monero badge remixes like Alien or Boss are undocumented and up to you to (re)create. Please mix and remix and send us a photo!

Q: How will sales proceeds be used?
A0: For buying a private jet or at least a model helicopter.
A1: Okay, profit(s) will fund development of next year's badge.

Q: Is a customer support email or phone offered?
A: No, you may seek information in any of Monero's IRC channels.

Q: Why do the badges cost so (little|much)?
A1: The regular badge price is about twice the small volume cost. After sales tax and XMR discount there is not much profit to speak of.
A2: The boss badge is expensive, because it is for those with means to help Monero Hardware proliferate the world.

Q: Is a battery required?
A1: Yes, but only for lights.
A2: No, the NFC circuit requires no power supply!

Q: Can I program my badge?
A: Yes! Learn how by attending the Monero Hardware programming workshop.

Q: Is this a Monero project?
A: Yes, more specifically it is a Monero Hardware project.

Q: Who made the badges?
A1: Cinnamonflower made the front graphics.
A2: Michael (MSvB) did the rest of the work.
A3: Ajs, Serhack, and Rehrar made web and documents.

Q: Will you make a badge for my conference?
A: Probably not, write to hardware@getmonero.org.

Q: Where is the Monero Village at Defcon 26?
A: It is called the BCOS/Monero Village and is located near the Defcon registration desk on the first floor of Caesars Palace.

Q: What is the intended purpose of the badge?
A1: There is no intended purpose, the badge is an experiment.
A2: Consider recognition by your community (graphic design.)
A3: Consider NFC storage of public information (VCards.)
A4: Consier eye pleasing nerdtainment (lights animation.)

Q: Why is the bage termed split brained?
A: There is neither communication nor energy shared across the lights and RF circuits.

Q: Is the defconfc badge distributed outside of Defcon?
A: Yes.

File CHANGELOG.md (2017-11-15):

Release zero
------------
Nothing changed

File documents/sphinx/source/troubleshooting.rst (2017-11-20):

Troubleshooting
===============

Morbi sed tempus libero. Donec et odio et mi bibendum tincidunt tincidunt sed ante. Vivamus in eleifend lorem. Nam vitae enim hendrerit, auctor augue a, maximus velit. Integer quis enim enim. Sed viverra felis quis ex molestie, sit amet sodales massa convallis. Ut in hendrerit lacus, ac pulvinar tortor. Fusce quis maximus ante. Cras et ligula felis.

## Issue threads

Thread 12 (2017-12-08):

directory firmware/trezour should read firmware/trezor

prusnak, 2017-12-08:
$title says it all

michaesc, 2017-12-19:
This is taking so long to resolve because we may completely delete the directory in question if it's not in use.

For months we've used word plays like ledgour, trezour, monezor, and similar. The 'our' in these names is not a typo but rather refers to 'our adaptation of ...'

If you understand this but still think it's better to rename to firmware/trezor just say so and the change will be forthcoming.

Thanks for taking the time to look around our repository, by the way. Very nice of you.

prusnak, 2017-12-19:
I did not realize it is a wordplay, okay then, closing :-)

Closed 2017-12-19.

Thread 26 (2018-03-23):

Enclosures needed?

morriswinkler, 2018-03-23:
I was working on an enclosure for the monezor.

Regarding the rather long list of hardware, what priorities do they have?
I just do want to prevent working on the wrong one?

```
antennas
breakneck
clonebox
clonedime
clonekeep
cloneledg
clonetrez
fpgalogic
monezor
utilities
```

michaesc, 2018-03-23:
Our bug reports (mistakenly called issuances by Github) are found on:

https://taiga.getmonero.org/project/michael-rfc-hwallet-1-implementation/issues/

...to which this GitHub area will automatically refer, once it's properly configured.

Hi Morris,

Since your question relates to a already documented task, please see task 161 for the answer to your question:

https://taiga.getmonero.org/project/michael-rfc-hwallet-1-implementation/task/161/

Thanks!
Michael

morriswinkler, 2018-03-23:
Just to sum up:

```
antennas
breakneck **
clonebox
clonedime
clonekeep
cloneledg
clonetrez
fpgalogic
monezor	**
utilities
```

Closed 2018-03-23.

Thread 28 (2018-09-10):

LGPL/AGPL violations

prusnak, 2018-09-10:
1) directory `firmware/monezor` contains Trezor code, which is LGPLv3 licensed, yet there is no COPYING file included in the directory. I suggest to add https://github.com/trezor/trezor-mcu/blob/master/COPYING file into this directory.

2) directory `hardware/monezor` contains designs based on Trezor design, which is AGPLv3 licensed. Via the nature of this license all files based on this design should be also AGPLv3 licensed. I suggest to add https://github.com/trezor/trezor-hw/blob/master/COPYING into this directory.

michaesc, 2018-10-05:
Hi Stick, thanks for noticing the missing COPYING file and good suggestion. The problem is now fixed in https://github.com/monero-project/kastelo/commit/1fe6d28

To determine if and where there is a hardware design license collision, please provide the AGPLv3 licensed source (not manufacturing) files for the schematic, BOM, and layout corresponding to our Monezor design. Monezor incorporates USB-C technology, so I'm assuming you are referring to the Trezor Model T design in your license comment number two.

prusnak, 2018-10-05:
Thanks for fixing the first issue.

As for the second issue, no, I am talking about Trezor One design. It is available from https://github.com/trezor/trezor-hw/ repo which is AGPLv3 licensed. Your design in `hardware/monezor` is clearly based on that particular design. Combination of usage STM32F205RET6 and MCP1703A clearly gives that fact away. We don't use these components in Trezor Model T.

michaesc, 2018-12-31:
As suggested, a COPYING file including AGPLv3 text was added in commit f705d85.

Closed 2018-12-31.

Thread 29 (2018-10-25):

USB type C identification failure

michaesc, 2018-10-25:
### Problem

Both Monezor and Breakneck suffer power negotiation and thus fail (unless a non USB power source is used) with some computer hosts.

### Suggestion

Load the CC (channel configuration) lines properly, to identify as a upstream facing port (peripheral) requiring power sink from the host.

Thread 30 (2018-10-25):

Route mechanical detector to ANTI_TAMP

michaesc, 2018-10-25:
### Anti-tamper Logic

The STM32 MCUs often have a pin called 'ANTI_TAMP' near GPIO PC13. Because we're trying to detect intrusion via a mechanical detector switch, it makes sense to reroute the existing PC4 trace to PC13 (or wherever ANTI_TAMP is specified.)

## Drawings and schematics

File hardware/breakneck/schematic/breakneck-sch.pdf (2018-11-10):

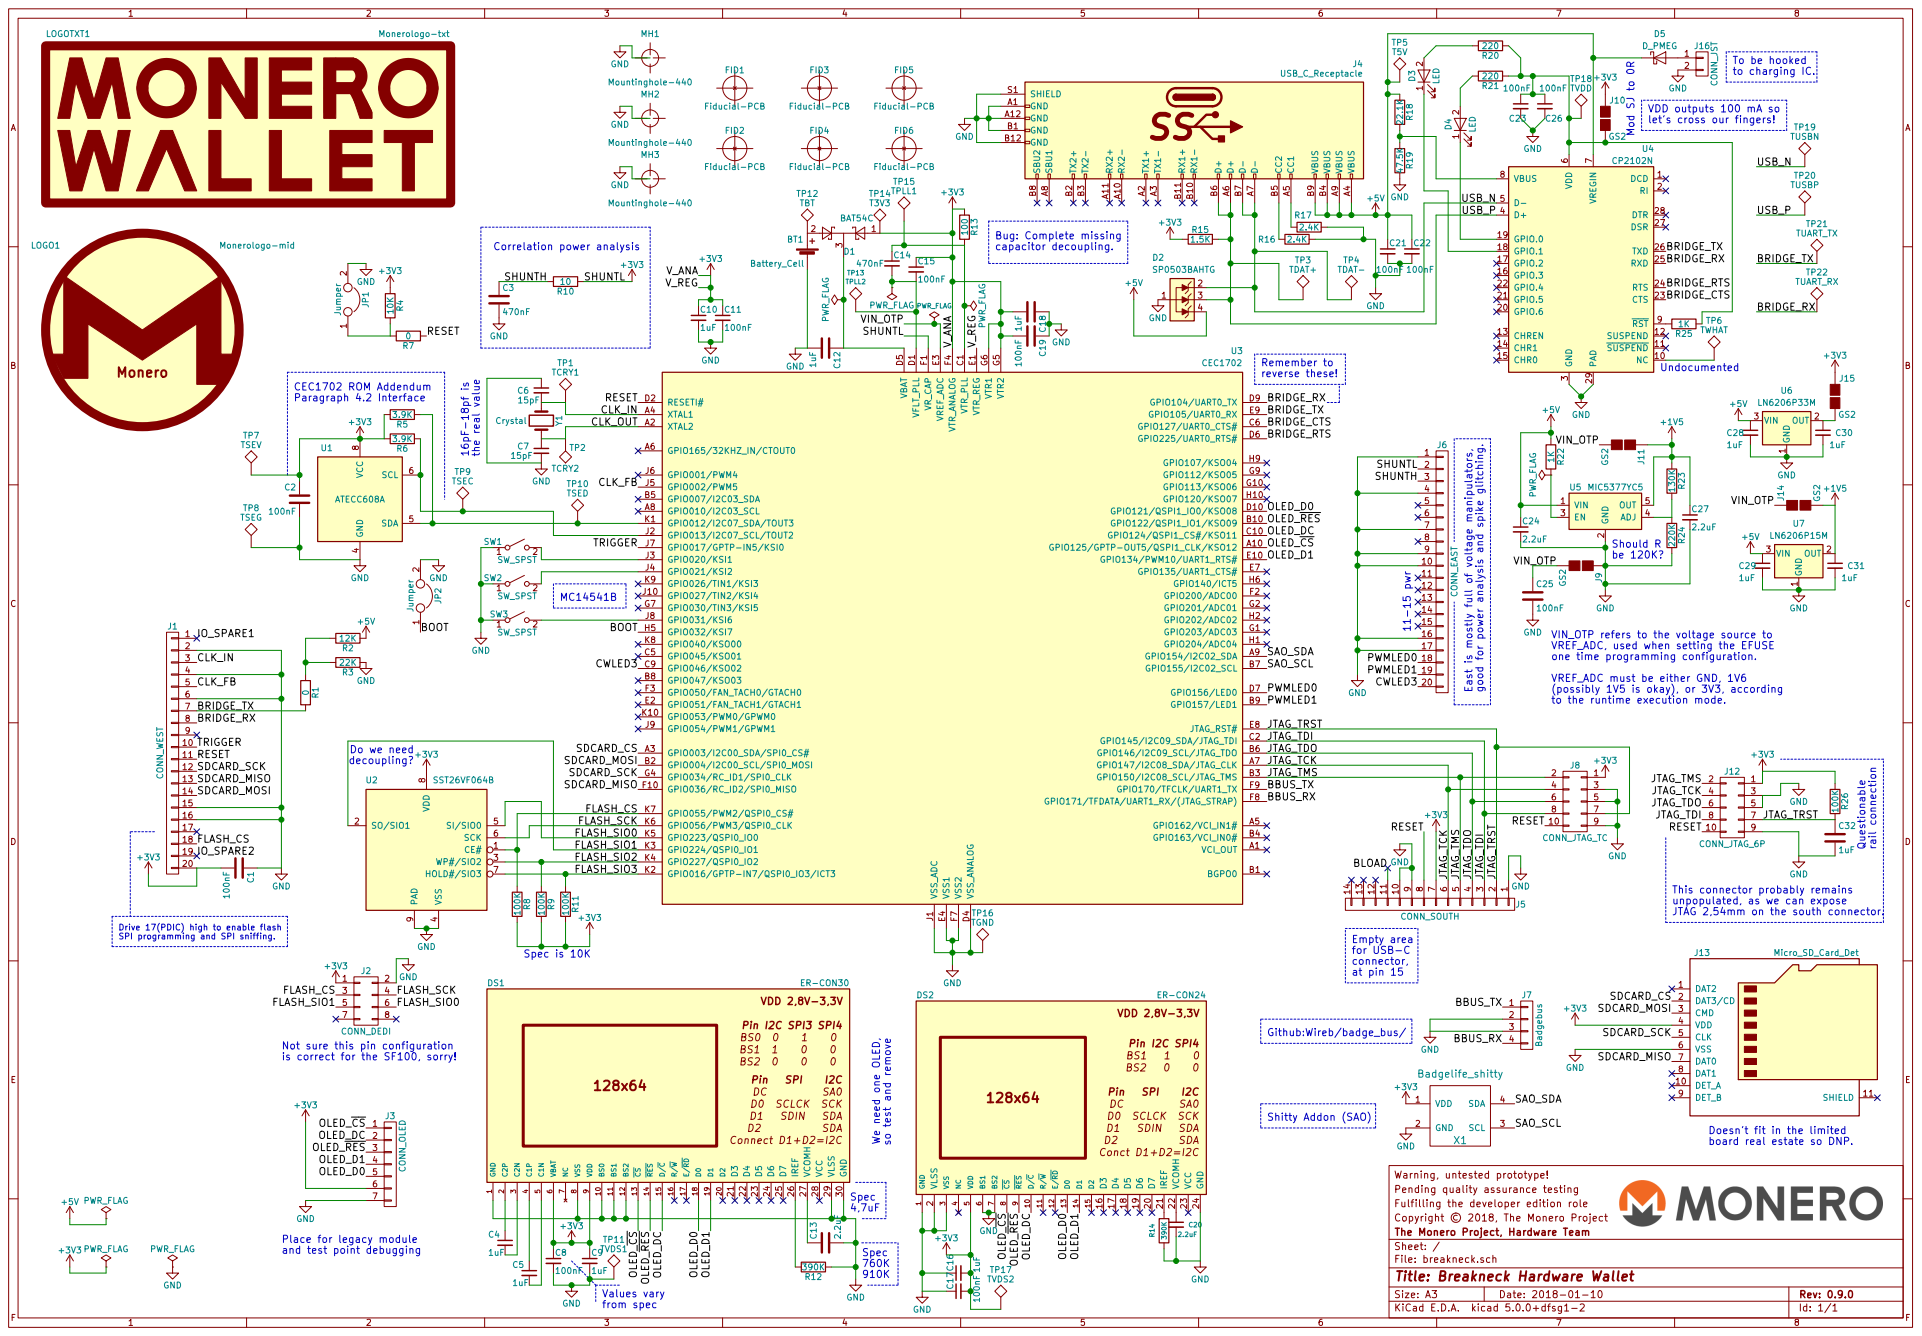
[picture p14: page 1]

let's cross our fingers! Remember to

VDD outputs 100 mA so

TP2 TCRY2 TP1 TCRY1 Drive 17(PDIC) high to enable flash
Monero

to the runtime execution mode. Should R

VIN_OTP refers to the voltage source to
VREF_ADC, used when setting the EFUSE
one time programming configuration.
VREF_ADC must be either GND, 1V6
(possibly 1V5 is okay), or 3V3, according

4 SI/SIO0 5 SCK 6 HOLD#/SIO3 7 VDD

This connector probably remains
unpopulated, as we can expose

SPI programming and SPI sniffing.

9 BS0 10 D2 20 GND 30 BS1 11 D3 21 BS2 12 D4 22 CS 13 D5 23 RES 14 D6 24 D/C 15 D7 25 R/W 16 IREF 26 E/RD 17 VCOMH 27 D0 18 VCC 28 D1 19 VLSS 29 DS1 ER-CON30GND
VDD 2,8V-3,3V GND

9 D/C 10 D7 20 R/W 11 IREF 21 E/RD 12 VCOMH 22 D0 13 VCC 23 D1 14 GND 24 D2 15 D3 16 D4 17 D5 18 D6 19 DS2 ER-CON24 GND GND

Not sure this pin configuration
is correct for the SF100, sorry!

2.2uF We need one OLED, so test and remove

board real estate so DNP.

Warning, untested prototype!
Pending quality assurance testing
Fulfilling the developer edition role
Copyright © 2018, The Monero Project
Id: 1/1 Title: Breakneck Hardware Wallet File: breakneck.sch Sheet: / The Monero Project, Hardware Team

and test point debugging

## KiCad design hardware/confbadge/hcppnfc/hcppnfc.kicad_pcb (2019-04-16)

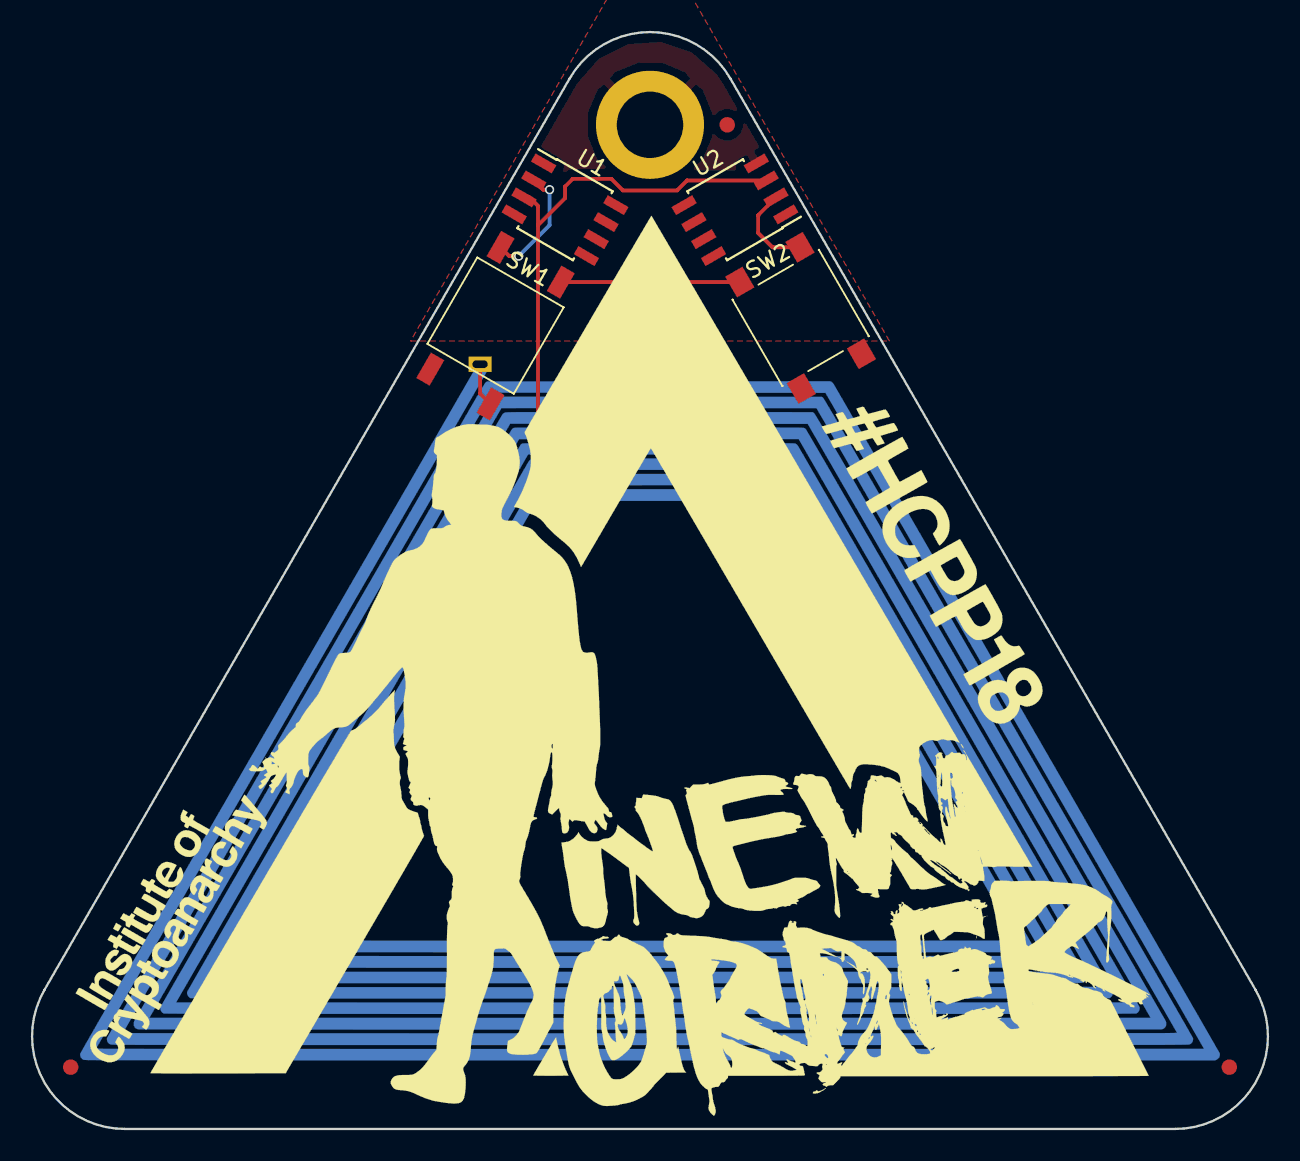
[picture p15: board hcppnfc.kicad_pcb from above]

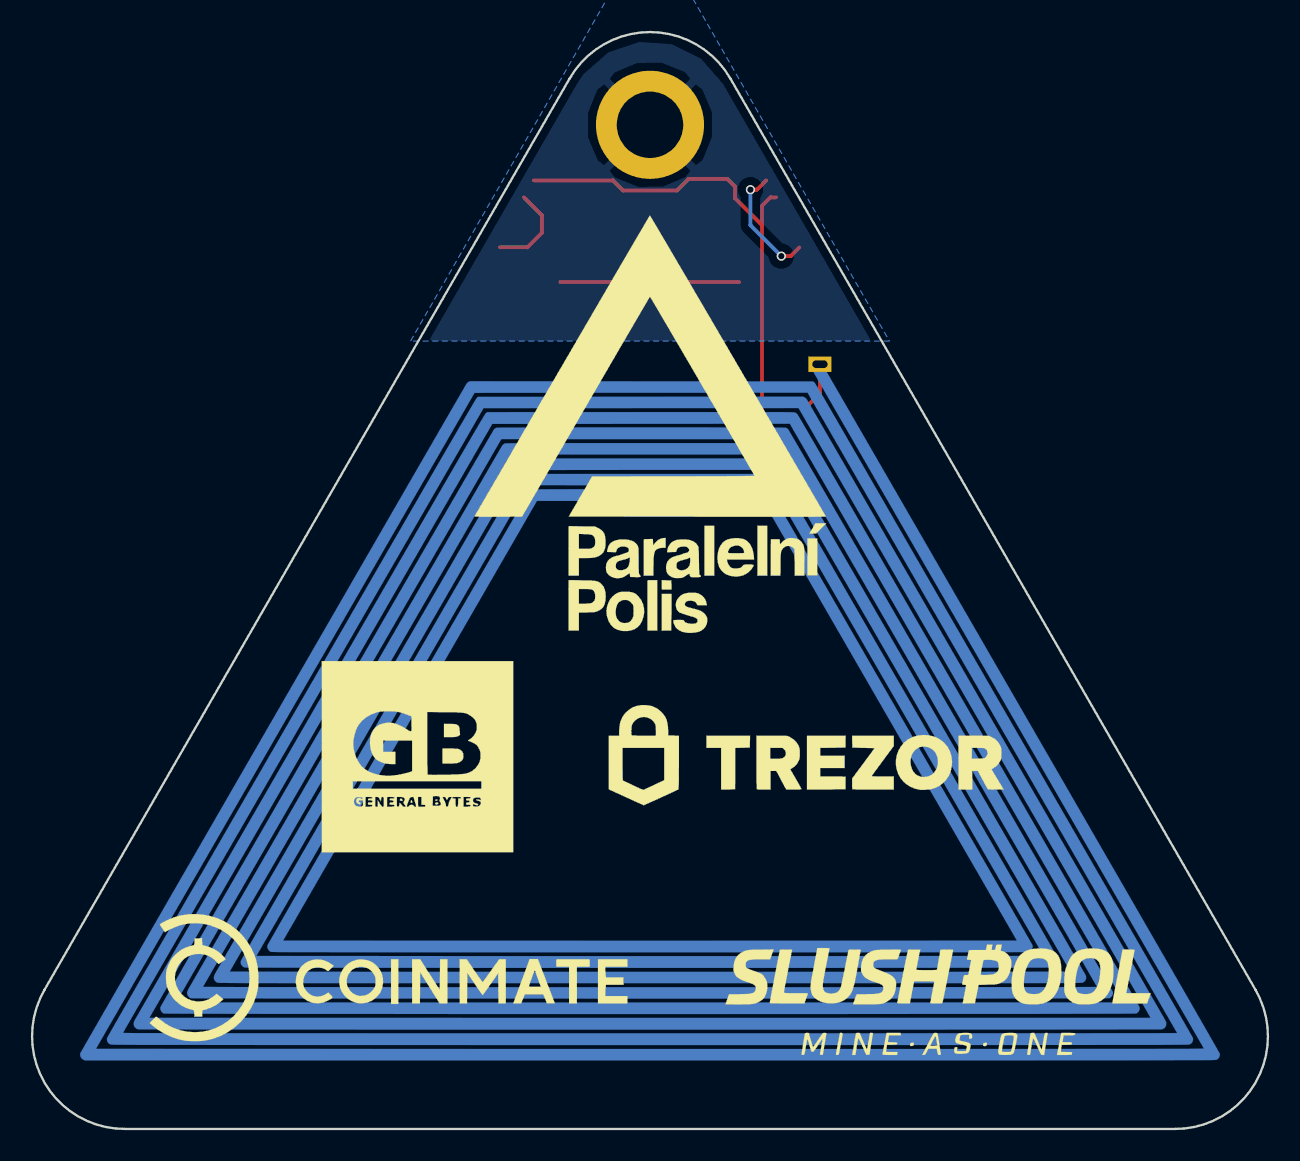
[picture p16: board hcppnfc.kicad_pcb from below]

Board: 2 copper layers, 80.0 x 71.0 mm, 13 parts (2 on the bottom side), 6 nets.

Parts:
AE1: Antenna_Loop; NFCAntennatall
FID1, FID2, FID3: Dummy_FIDUCIAL_Passermarke_Type1_RevE_Date16Nov20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; Fiducial_1mm_Dia_2mm_Outer
GFX*: ART_TRIANGLE; HCPPNewordtri
GFX*#2: ART_CONFYEAR; HCPPNewordconf
GFX*#3: ART_INSTCRYP; HCPPNewordinst
LOGO*: LOGO; HCPPSponsors
MH1: DUMMY_MOUNTING-HOLE_RevE_Date22jun2010; MountingHole_4.3mm_M4_ISO14580_Pad
SW1: SW_SPST; SW_SPST_K21102SP
SW2: SW_SPST; SW_SPST_PTS645
U1, U2: M24SR02-YMN; SOIC-8_3.9x4.9mm_Pitch1.27mm

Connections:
/ANTCON: AE1.2, U1.3, U2.3
GND: MH1.1, U1.4, U2.4
unnamed: AE1.1, SW1.1, SW2.1
unnamed: SW1.2, U1.2
unnamed: SW2.2, U2.2
VCC: U1.8, U2.8

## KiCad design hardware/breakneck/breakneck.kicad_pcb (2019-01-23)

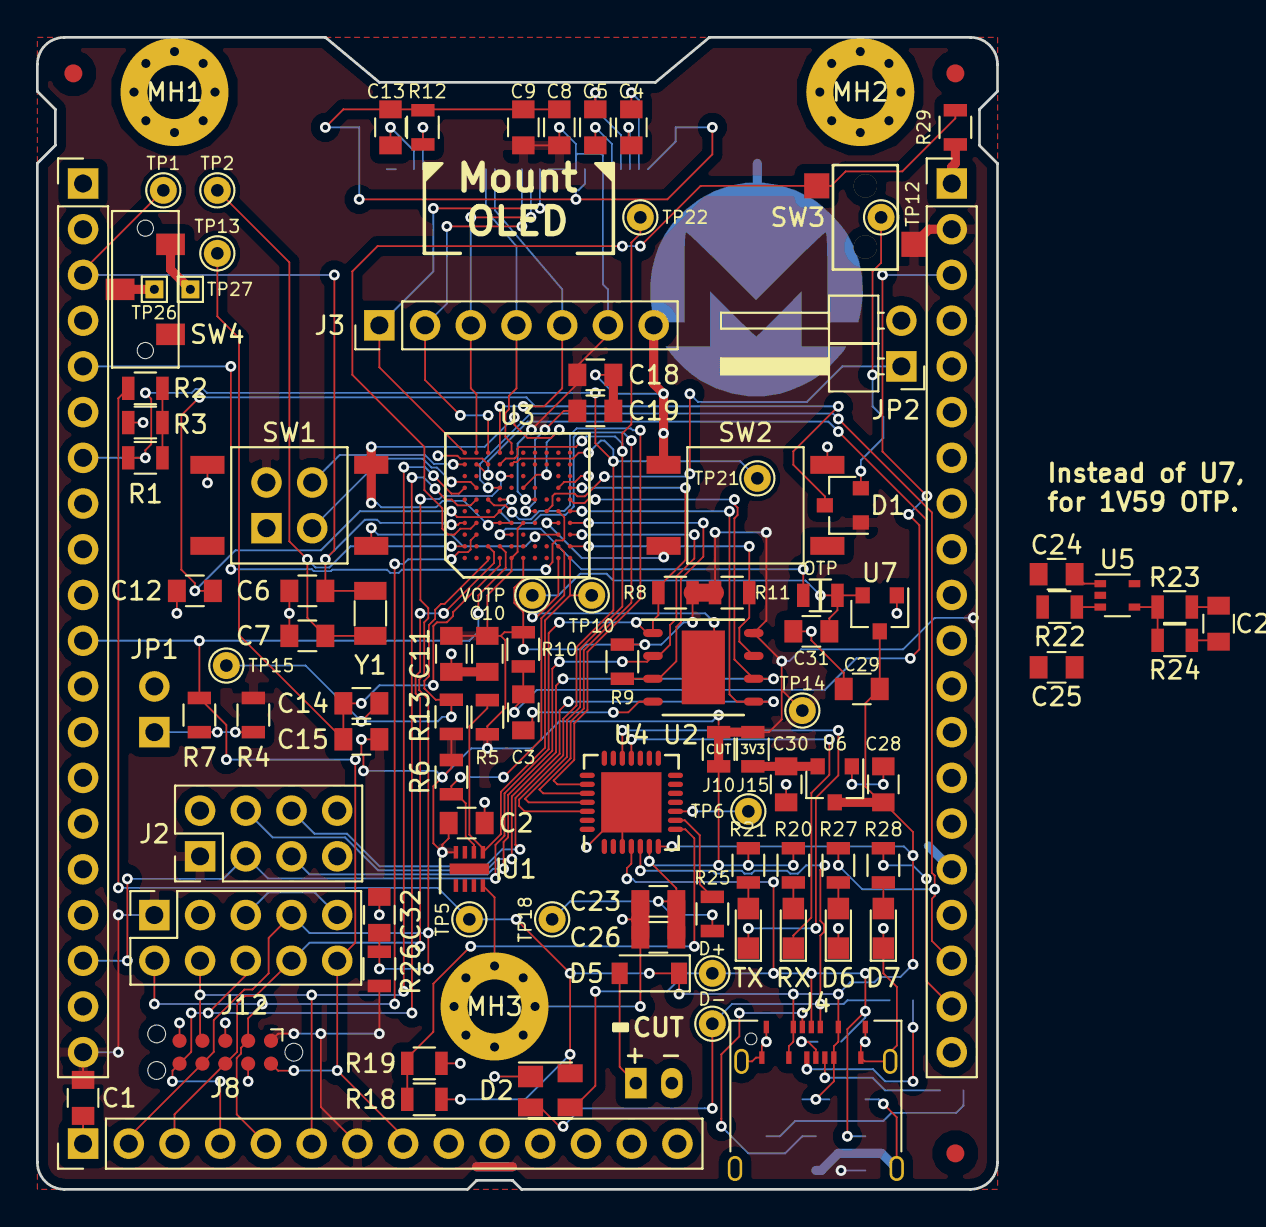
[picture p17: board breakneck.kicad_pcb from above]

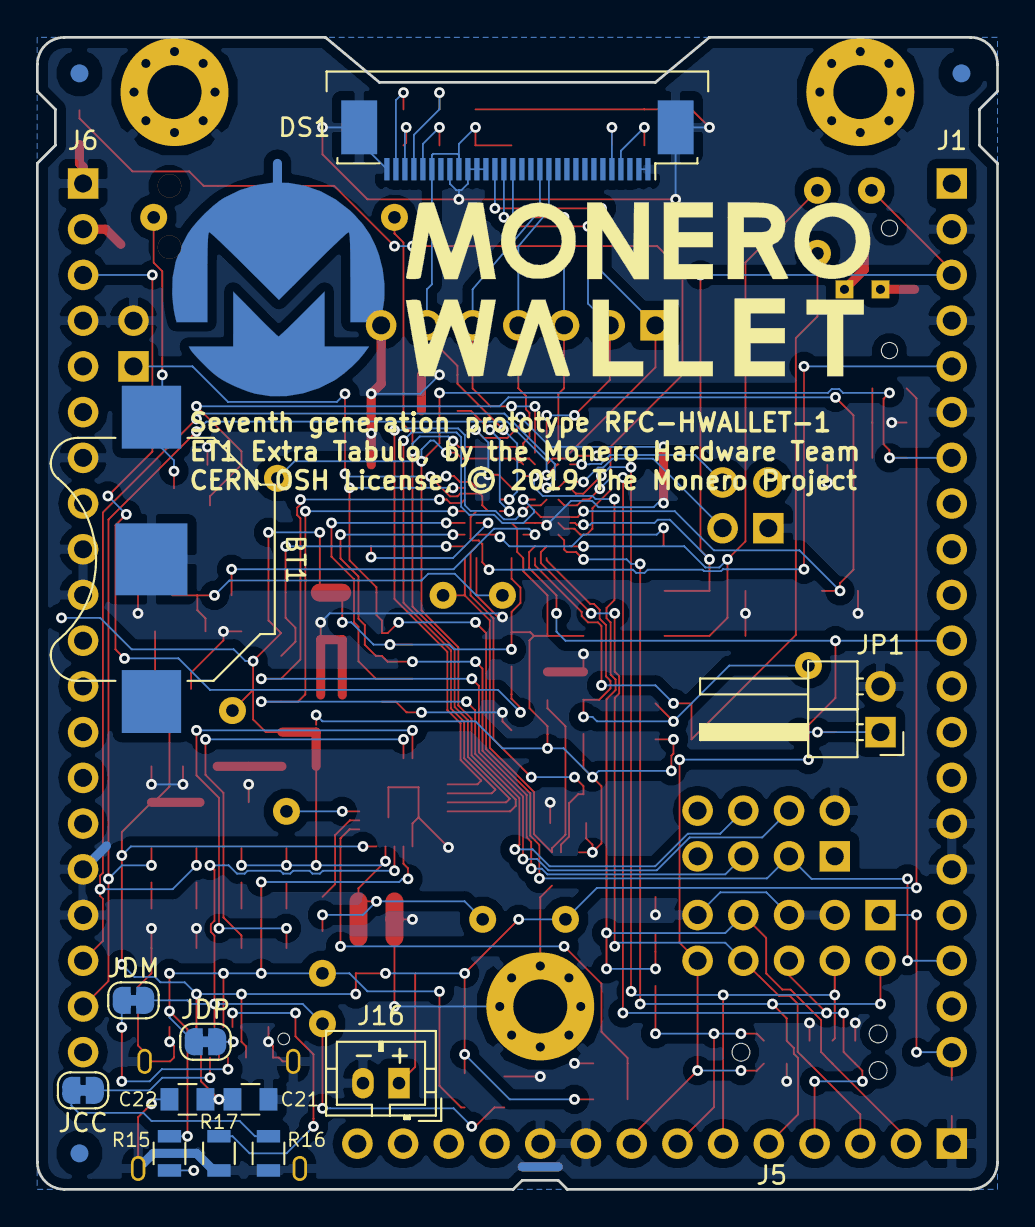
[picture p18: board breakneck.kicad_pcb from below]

Board: 2 copper layers, 53.3 x 64.0 mm, 124 parts (17 on the bottom side), 79 nets.

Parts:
BT1: Battery_Cell; Keystone_3000_1x12mm-CoinCell
C1, C2, C8, C11, C15, C19, C21, C22, C23, C25, C26: 100nF; C_0805
C3, C14: 470nF; C_0805
C4, C5, C9, C10, C12, C18, C28, C29, C30, C31, C32: 1uF; C_0805
C6, C7: 15pF; C_0805
C13, C24, C27: 2.2uF; C_0805
D1: BAT54C; SOT-23
D2: SP0503BAHTG; SOT-143
D5: D_PMEG; D_SOD-123
D6, D7: LED; LED_0805
D+: TUSBP; TestPoint_THTPad_D1.5mm_Drill0.7mm
D-: TUSBN; TestPoint_THTPad_D1.5mm_Drill0.7mm
DS1: ER-CON30; Eastrising_ER-CON30HT-1_01x30_P0.50mm
FID1, FID2, FID3, FID4, FID5, FID6: Fiducial-PCB; Fiducial_1mm_Dia_2.54mm_Outer_CopperTop
J1: CONN_WEST; Pin_Header_Straight_1x20_Pitch2.54mm
J2: CONN_DEDI; Pin_Header_Straight_2x04_Pitch2.54mm
J3: CONN_OLED; Socket_Strip_Straight_1x07_Pitch2.54mm
J4: USB_C_Rcpt_Min; USBC_Rcpt_Min_12401610E4-2A
J5: CONN_SOUTH; Pin_Header_Straight_1x14_Pitch2.54mm
J6: CONN_EAST; Pin_Header_Straight_1x20_Pitch2.54mm
J8: CONN_JTAG_TC; Tag-Connect_TC2050-IDC-NL
J10, J15: GS2; R_0805
J12: CONN_JTAG_6P; PinSocket_2x05_P2.54mm_Vertical
J16: CONN_JST; JST_PH_B2B-PH-K_02x2.00mm_Straight
JCC: SJC2; Solderjump-2NCRndpad
JDM: SJC2; Solderjump-2NCRndpad
JDP: SJC2; Solderjump-2NCRndpad
JP1, JP2: Jumper; Pin_Header_Angled_1x02_Pitch2.54mm
LOGO1: Monerologo-mid; MoneroCircleCombi
LOGOTXT1: Monerologo-txt; MoneroTextSilk
MH1, MH2, MH3: Mountinghole-440; MountingHole_3mm_Pad_Via
OTP: 150; R_0805
R1, R7: 0; R_0805
R2: 12K; R_0805
R3: 22K; R_0805
R4, R29: 10K; R_0805
R5, R6: 3.9K; R_0805
R8, R9, R11, R26: 100K; R_0805
R10: 10; R_0805
R12: 390K; R_0805
R13: 100; R_0805
R15: 1.5K; R_0805
R16, R17: 2.4K; R_0805
R18: 22.1K; R_0805
R19: 47.5K; R_0805
R20, R21: 220; R_0805
R22, R25: 1K; R_0805
R23: 130K; R_0805
R24: 220K; R_0805
R27, R28: 150; R_0805
RX: LED; LED_0805
SW1, SW2: SW_SPST; SW_SPST_K21102SP
SW3: SW_SPST; SW_SPST_ESE11MV1
SW4: SW_SPDT; SW_SPDT_CLSB-12A
TP1: TCRY1; TestPoint_THTPad_D1.5mm_Drill0.7mm
TP2: TCRY2; TestPoint_THTPad_D1.5mm_Drill0.7mm
TP5: T5V; TestPoint_THTPad_D1.5mm_Drill0.7mm
TP6: TWHAT; TestPoint_THTPad_D1.5mm_Drill0.7mm
TP10: TSED; TestPoint_THTPad_D1.5mm_Drill0.7mm
TP12: TBT; TestPoint_THTPad_D1.5mm_Drill0.7mm
TP13: TPLL2; TestPoint_THTPad_D1.5mm_Drill0.7mm
TP14: T3V3; TestPoint_THTPad_D1.5mm_Drill0.7mm
TP15: TPLL1; TestPoint_THTPad_D1.5mm_Drill0.7mm
TP18: TVDD; TestPoint_THTPad_D1.5mm_Drill0.7mm
TP21: TUART_TX; TestPoint_THTPad_D1.5mm_Drill0.7mm
TP22: TUART_RX; TestPoint_THTPad_D1.5mm_Drill0.7mm
TP26, TP27: TEST; TestPoint_THTPad_1.0x1.0mm_Drill0.5mm
TX: LED; LED_0805
U1: ATECC508A; DFN-8-1EP_2x3mm_Pitch0.5mm
U2: SST26VF064B; DFN-S-8-1EP_6x5mm_Pitch1.27mm
U3: CEC1702; WFBGACEC1702
U4: CP2102N; QFN-28-1EP_5x5mm_Pitch0.5mm
U5: MIC5377YC5; SOT-353_SC-70-5
U6: LN6206P33M; SOT-23
U7: LN6206P15M; SOT-23
VOTP: VOTP; TestPoint_THTPad_D1.5mm_Drill0.7mm
X1: Badgelife_shitty; Badgelife-Shitty-2x2
Y1: Crystal; Crystal_SMD_3215-2Pin_3.2x1.5mm

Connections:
+1V5: C27.1, C31.1, OTP.2, R23.1, U5.5, U7.2, VOTP.1
+3V3: C1.2, C2.1, C8.1, C9.1, C10.1, C11.1, C15.1, C18.2, C19.2, D1.1, DS1.6, DS1.9, J1.20, J2.1, J3.6, J5.7, J6.2, J8.1, J10.1, J12.1, J15.1, R4.1, R5.2, R6.2, R8.2, R9.2, R10.1, R11.2, R13.1, R15.2, R26.1, SW3.2, TP14.1, U1.8, U2.8, U3.E1, U3.F1, U3.F4, U3.G5, U3.G6, X1.1
+5V: C21.1, C22.1, C24.1, C28.1, C29.1, D2.4, D5.1, J4.A4, J4.A9, J4.B4, J4.B9, R2.2, R18.1, R22.1, TP5.1, U4.7, U5.1, U6.3, U7.3
/BOOT: JP2.1, U3.H5
/BRIDGE_CTS: U3.C6, U4.23
/BRIDGE_RTS: U3.D6, U4.24
/BRIDGE_RX: J1.8, TP22.1, U3.D9, U4.25
/BRIDGE_TX: J1.7, R1.2, TP21.1, U3.E9, U4.26
/CLK_FB: J1.5, U3.J5
/CLK_IN: C6.2, J1.3, TP1.1, U3.A4, Y1.1
/CLK_OUT: C7.1, TP2.1, U3.A2, Y1.2
/CWLED3: J6.20, U3.C9
/FLASH_CS: J1.18, J2.3, R8.1, U2.1, U3.K7
/FLASH_SCK: J2.4, U2.6, U3.K6
/FLASH_SIO0: J2.6, U2.5, U3.K5
/FLASH_SIO1: J2.5, U2.2, U3.K3
/FLASH_SIO2: R9.1, U2.3, U3.K4
/FLASH_SIO3: R11.1, U2.7, U3.K2
/JTAG_TCK: J5.6, J8.4, J12.4, U3.A7
/JTAG_TDI: J5.3, J8.8, J12.8, U3.C2
/JTAG_TDO: J5.4, J8.6, J12.6, U3.B6
/JTAG_TMS: J5.5, J8.2, J12.2, U3.B3
/JTAG_TRST: C32.1, J5.2, J8.7, J12.7, R26.2, U3.E8
/OLED_D0: DS1.18, J3.5, U3.D10
/OLED_D1: DS1.19, J3.4, U3.E10
/OLED_DC: DS1.15, J3.2, U3.C10
/OLED_~CS~: DS1.13, J3.1, U3.A10
/OLED_~RES~: DS1.14, J3.3, U3.B10
/PWMLED0: J6.18, R27.2, U3.D7
/PWMLED1: J6.19, R28.2, U3.B9
/RESET: J1.11, J5.8, J8.10, J12.10, R7.1, U3.D2
/SAO_SCL: U3.B7, X1.3
/SAO_SDA: U3.A9, X1.4
/SDCARD_MISO: J1.13, U3.F10
/SDCARD_MOSI: J1.14, U3.B2
/SDCARD_SCK: J1.12, U3.G4
/SHUNTH: C3.1, J6.3, R10.2
/TRIGGER: J1.10, U3.J7
/USB_N: D2.2, D-.1, J4.A7, JDM.2, U4.5
/USB_P: D2.3, D+.1, J4.A6, JDP.2, R15.1, U4.4
/VIN_OTP: C25.1, OTP.1, U3.E3
GND: BT1.2, C1.1, C2.2, C3.2, C6.1, C7.2, C8.2, C9.2, C10.2, C11.2, C12.2, C13.2, C18.1, C19.1, C21.2, C22.2, C23.2, C24.2, C25.2, C26.2, C27.2, C28.2, C29.2, C30.2, C31.2, C32.2, D2.1, D6.1, D7.1, DS1.1, DS1.8, DS1.10, DS1.11, DS1.12, DS1.29, DS1.30, J1.2, J1.4, J1.6, J1.15, J1.16, J2.2, J3.7, J4.A1, J4.A12, J4.B1, J4.B12, J4.S1, J5.1, J5.9, J5.10, J6.1, J6.4, J6.7, J6.9, J6.10, J6.16, J6.17, J8.3, J8.5, J8.9, J12.3, J12.5, J12.9, J16.2, JP1.2, JP2.2, MH1.1, MH2.1, MH3.1, R3.1, R12.1, R16.1, R17.1, R19.2, R24.2, R29.1, SW1.1, SW2.1, U1.4, U2.4, U2.9, U3.D4, U3.E4, U3.F7, U3.J1, U4.3, U4.29, U5.2, U6.1, U7.1, X1.2
unnamed: BT1.1, D1.2, TP12.1
unnamed: C4.1, DS1.2
unnamed: C4.2, DS1.3
unnamed: C5.1, DS1.4
unnamed: C5.2, DS1.5
unnamed: C12.1, D1.3, U3.D5
unnamed: C13.1, DS1.27
unnamed: C14.1, R13.2, TP15.1, U3.C1
unnamed: C14.2, C15.2, TP13.1, U3.D1
unnamed: C23.1, C26.1, J10.2, R20.1, R21.1, R25.1, TP18.1, U4.6
unnamed: C30.1, J15.2, U6.2
unnamed: RX.1, U4.18
unnamed: R20.2, RX.2
unnamed: TX.1, U4.19
unnamed: R21.2, TX.2
unnamed: D5.2, SW4.2, TP26.1
unnamed: D6.2, R27.1
unnamed: D7.2, R28.1
unnamed: DS1.26, R12.2
unnamed: J4.A5, R17.2
unnamed: J4.B5, JCC.1
unnamed: J4.B6, JDP.1
unnamed: J4.B7, JDM.1
unnamed: J16.1, SW4.3, TP27.1
unnamed: JP1.1, R4.2, R7.2
unnamed: JCC.2, R16.2
unnamed: R1.1, R2.1, R3.2
unnamed: R5.1, TP10.1, U1.5, U3.K1
unnamed: R6.1, U1.6, U3.J2
unnamed: R18.2, R19.1, U4.8
unnamed: R22.2, U5.3
unnamed: R23.2, R24.1, U5.4
unnamed: R25.2, U4.9
unnamed: R29.2, SW3.1, U3.B4
unnamed: SW1.2, U3.J3
unnamed: SW2.2, U3.J4
unnamed: TP6.1, U4.10

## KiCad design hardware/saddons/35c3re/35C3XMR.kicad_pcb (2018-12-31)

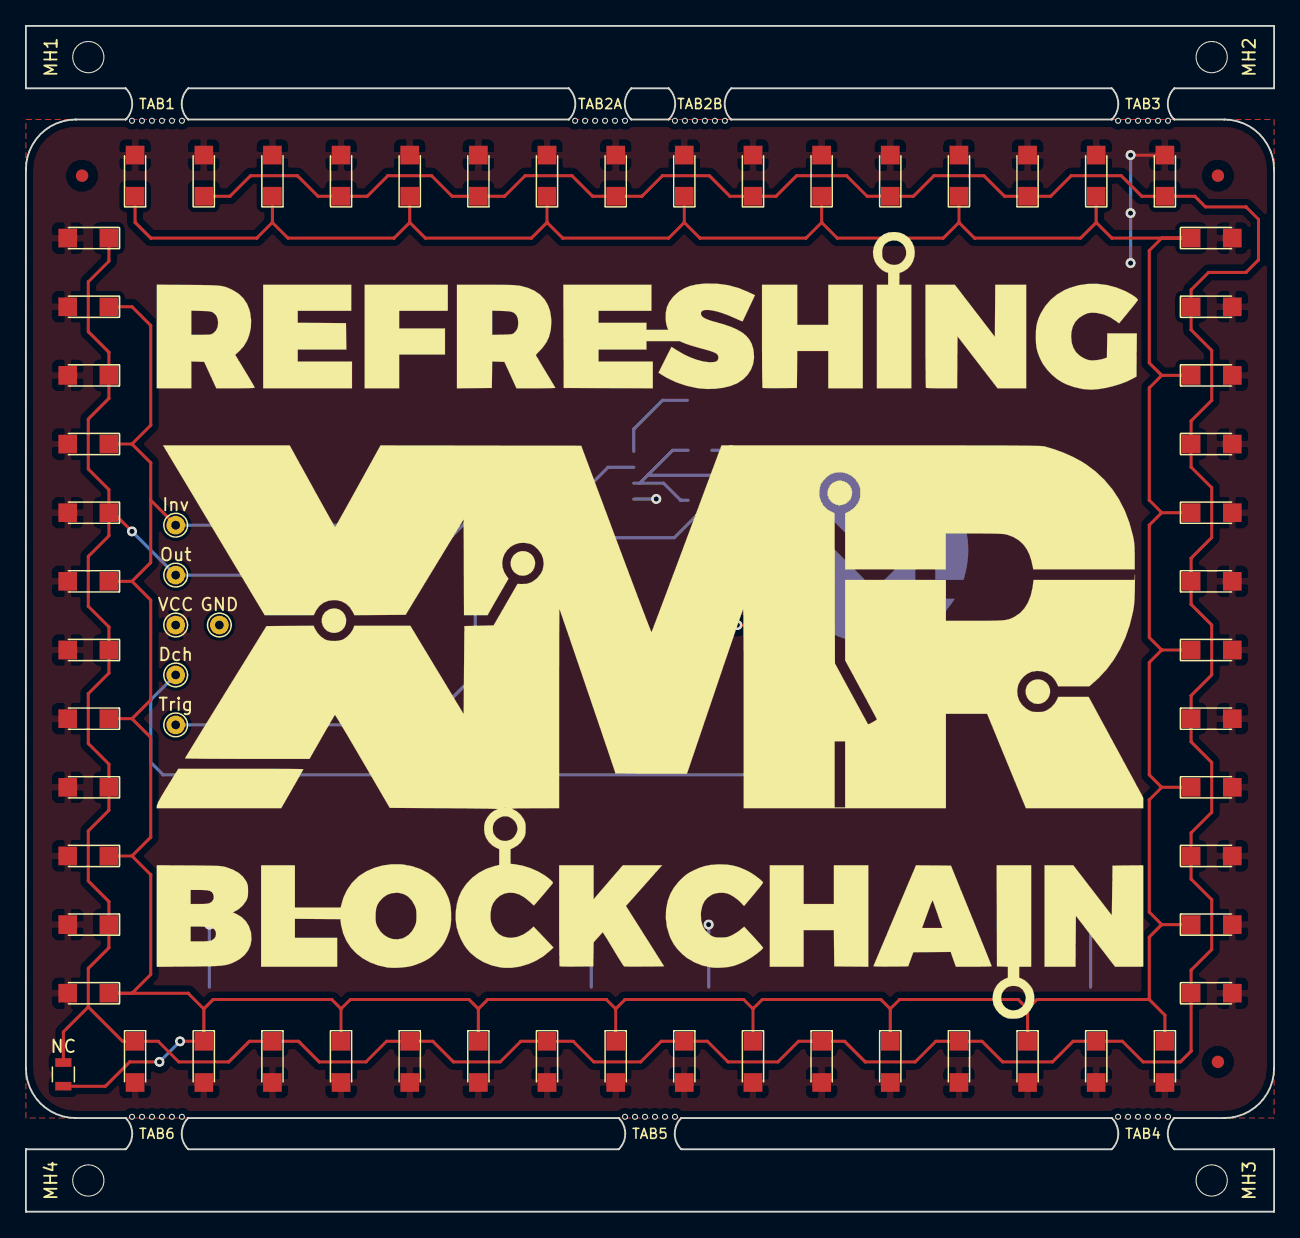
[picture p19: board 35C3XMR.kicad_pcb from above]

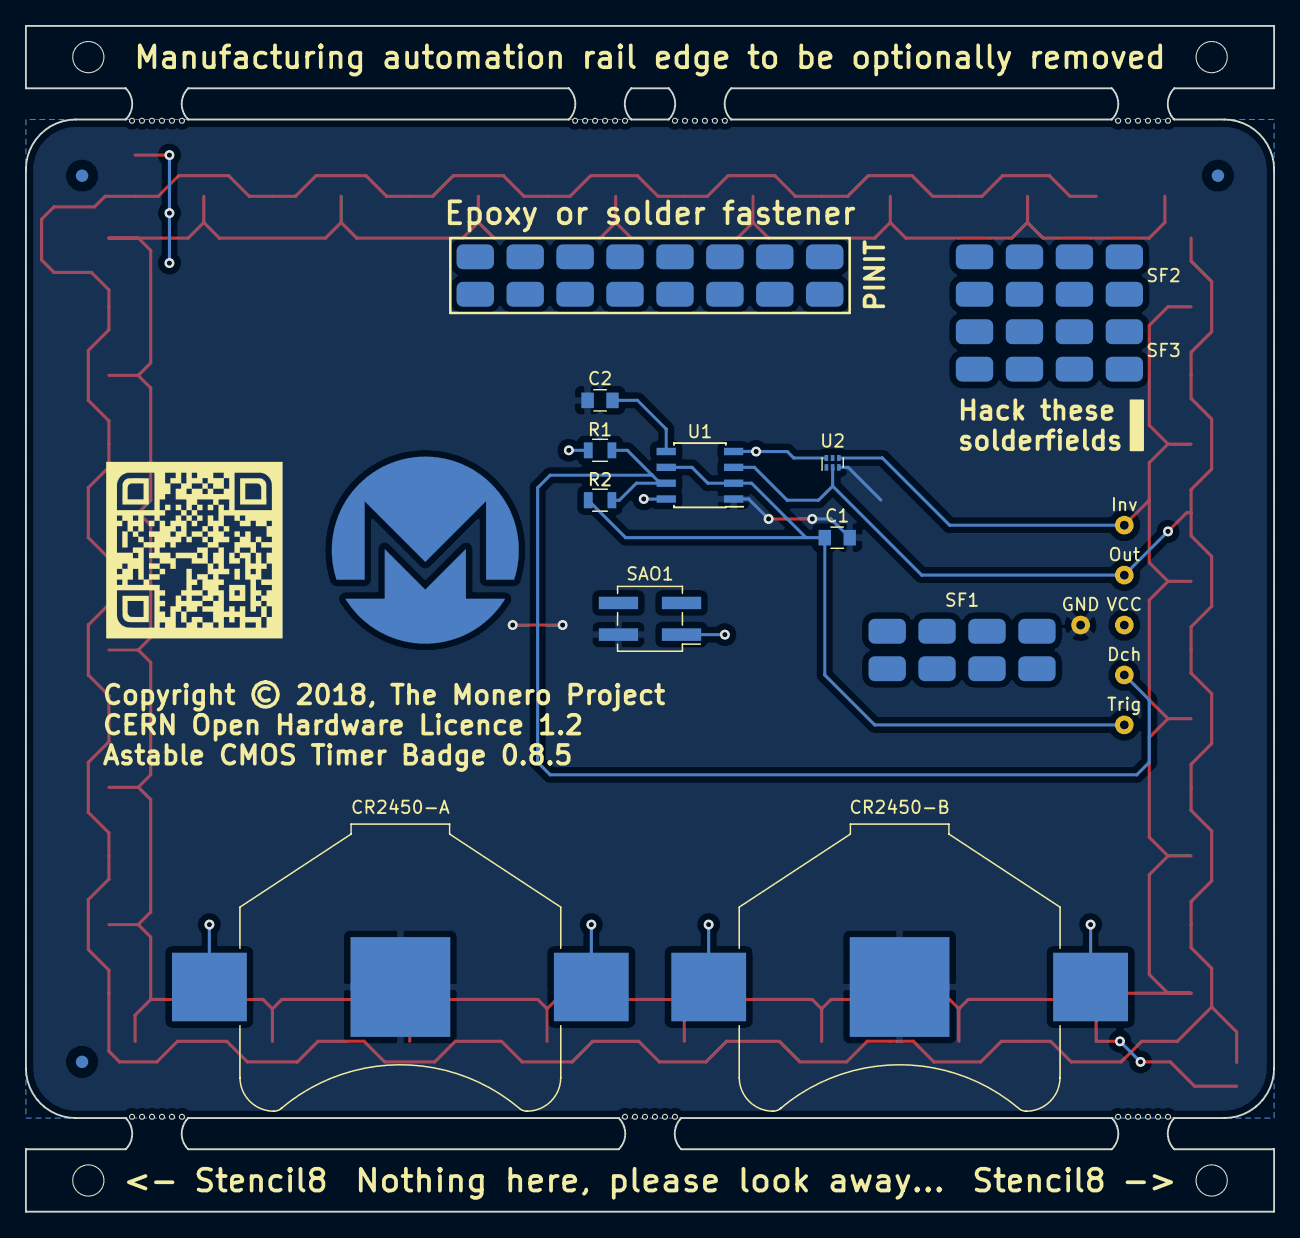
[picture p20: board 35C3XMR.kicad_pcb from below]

Board: 2 copper layers, 100.0 x 95.0 mm, 97 parts (19 on the bottom side), 7 nets.

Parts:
C1: 4,7uF; C_0805
C2: ,01uF; C_0805
CR2450-A, CR2450-B: Battery_Cell; BatteryHolder_Keystone_3008_1x2450
D1, D2, D3, D4, D5, D6, D7, D8, D9, D10, D11, D12, D13, D14, D15, D16, D17, D18, D19, D20, D21, D22, D23, D24, D25, D26, D27, D28, D29, D30, D31, D32, D33, D34, D35, D36, D37, D38, D39, D40, D41, D42, D43, D44, D45, D46, D47, D48, D49, D50, D51, D52, D53, D54, D55, D56: LED; LED_1206
Dch: TEST; TestPoint_THTPad_D1.5mm_Drill0.7mm
FID1, FID3, FID5: FiducialPassermarke-Top; Fiducial_1mm_Dia_2.54mm
FID2, FID4, FID6: FiducialPassermarke-Bot; Fiducial_1mm_Dia_2.54mm
G1: QRCOD; Kastelospecsqr
GND: TEST; TestPoint_THTPad_D1.5mm_Drill0.7mm
Inv: TEST; TestPoint_THTPad_D1.5mm_Drill0.7mm
LOGO1: 35C3Logo-funny; 35C3Funny
LOGO2: Moneroball; Moneroball_15mm
MH1, MH2, MH3, MH4: MountingHole_2.5mm
NC: Jumper; R_0805
Out: TEST; TestPoint_THTPad_D1.5mm_Drill0.7mm
R1: 10K; R_0805
R2: 100K; R_0805
SAO1: Shitty_conn; PinHeader_2x02_P2.54mm_Vertical_SMD
SF1, SF2, SF3, SF4, SF5: Soldfeld; Solderarea
TAB1, TAB2A, TAB2B, TAB3, TAB4, TAB5, TAB6: Panel_Mousetab_25mm_Single
Trig: TEST; TestPoint_THTPad_D1.5mm_Drill0.7mm
U1: TLC555; SOIC-8_3.9x4.9mm_P1.27mm
U2: NC7SZ04L6X; Fairchild_MicroPak-6_1.0x1.45mm_P0.5mm
VCC: TEST; TestPoint_THTPad_D1.5mm_Drill0.7mm

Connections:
+3V3: CR2450-A.1, CR2450-B.1, D1.2, D2.2, D3.2, D4.2, D5.2, D6.2, D7.2, D8.2, D9.2, D10.2, D11.2, D12.2, D13.2, D14.2, D15.2, D16.2, D17.2, D18.2, D19.2, D20.2, D21.2, D22.2, D23.2, D24.2, D25.2, D26.2, D27.2, D28.2, D29.2, D30.2, D31.2, D32.2, D33.2, D34.2, D35.2, D36.2, D37.2, D38.2, D39.2, D40.2, D41.2, D42.2, D43.2, D44.2, D45.2, D46.2, D47.2, D48.2, D49.2, D50.2, D51.2, D52.2, D53.2, D54.2, D55.2, D56.2, R1.2, SAO1.1, U1.4, U1.8, U2.6, VCC.1
GND: C1.2, C2.2, CR2450-A.2, CR2450-B.2, GND.1, SAO1.2, U1.1, U2.3
unnamed: C1.1, R2.2, Trig.1, U1.2, U1.6
unnamed: C2.1, U1.5
unnamed: D1.1, D3.1, D5.1, D7.1, D9.1, D11.1, D13.1, D15.1, D17.1, D19.1, D21.1, D23.1, D25.1, D27.1, D29.1, D31.1, D33.1, D35.1, D37.1, D39.1, D41.1, D43.1, D45.1, D47.1, D49.1, D51.1, D53.1, D55.1, Inv.1, NC.2, U2.4
unnamed: D2.1, D4.1, D6.1, D8.1, D10.1, D12.1, D14.1, D16.1, D18.1, D20.1, D22.1, D24.1, D26.1, D28.1, D30.1, D32.1, D34.1, D36.1, D38.1, D40.1, D42.1, D44.1, D46.1, D48.1, D50.1, D52.1, D54.1, D56.1, NC.1, Out.1, U1.3, U2.2
unnamed: Dch.1, R1.1, R2.1, U1.7

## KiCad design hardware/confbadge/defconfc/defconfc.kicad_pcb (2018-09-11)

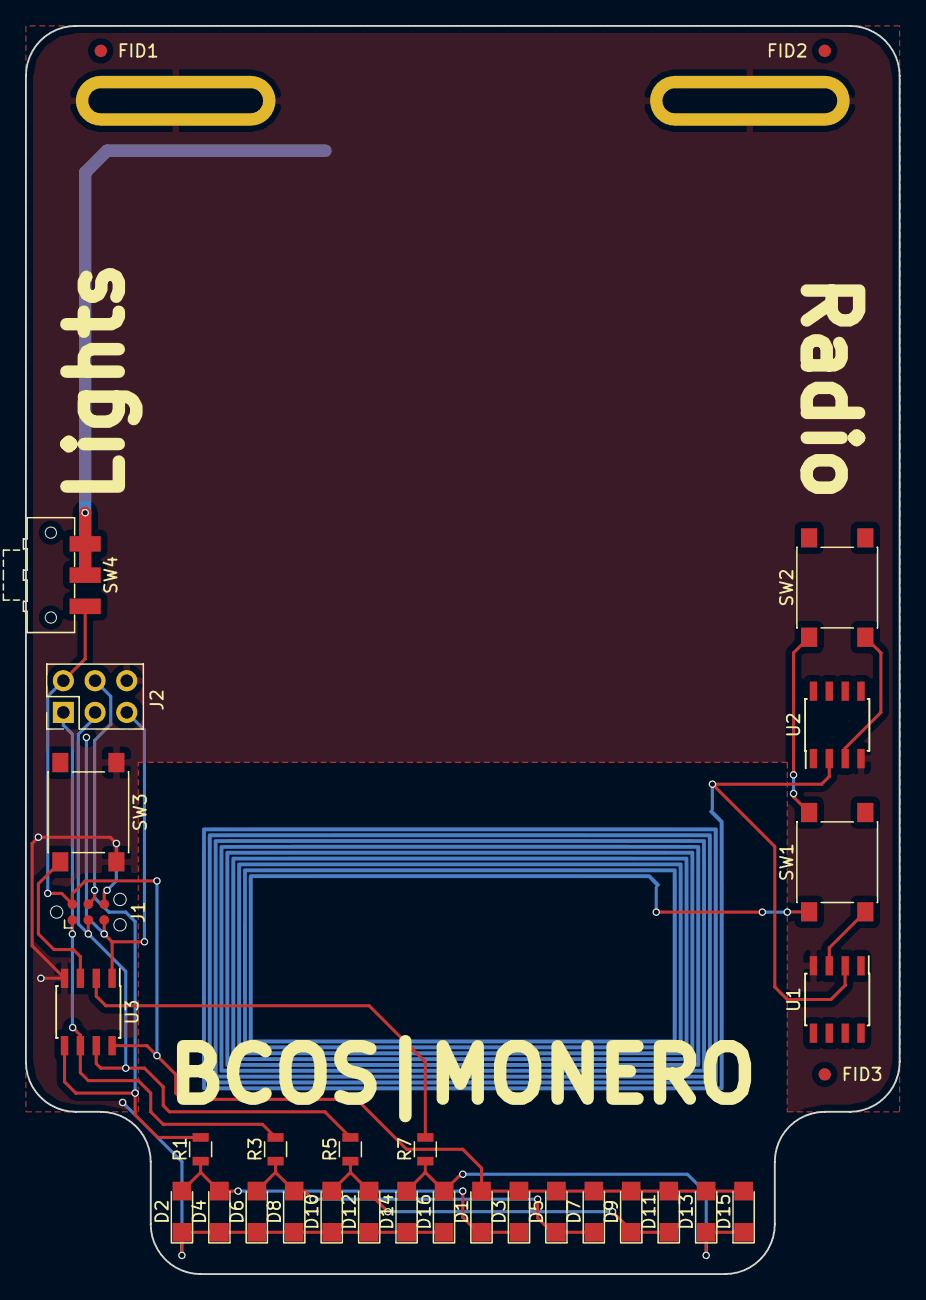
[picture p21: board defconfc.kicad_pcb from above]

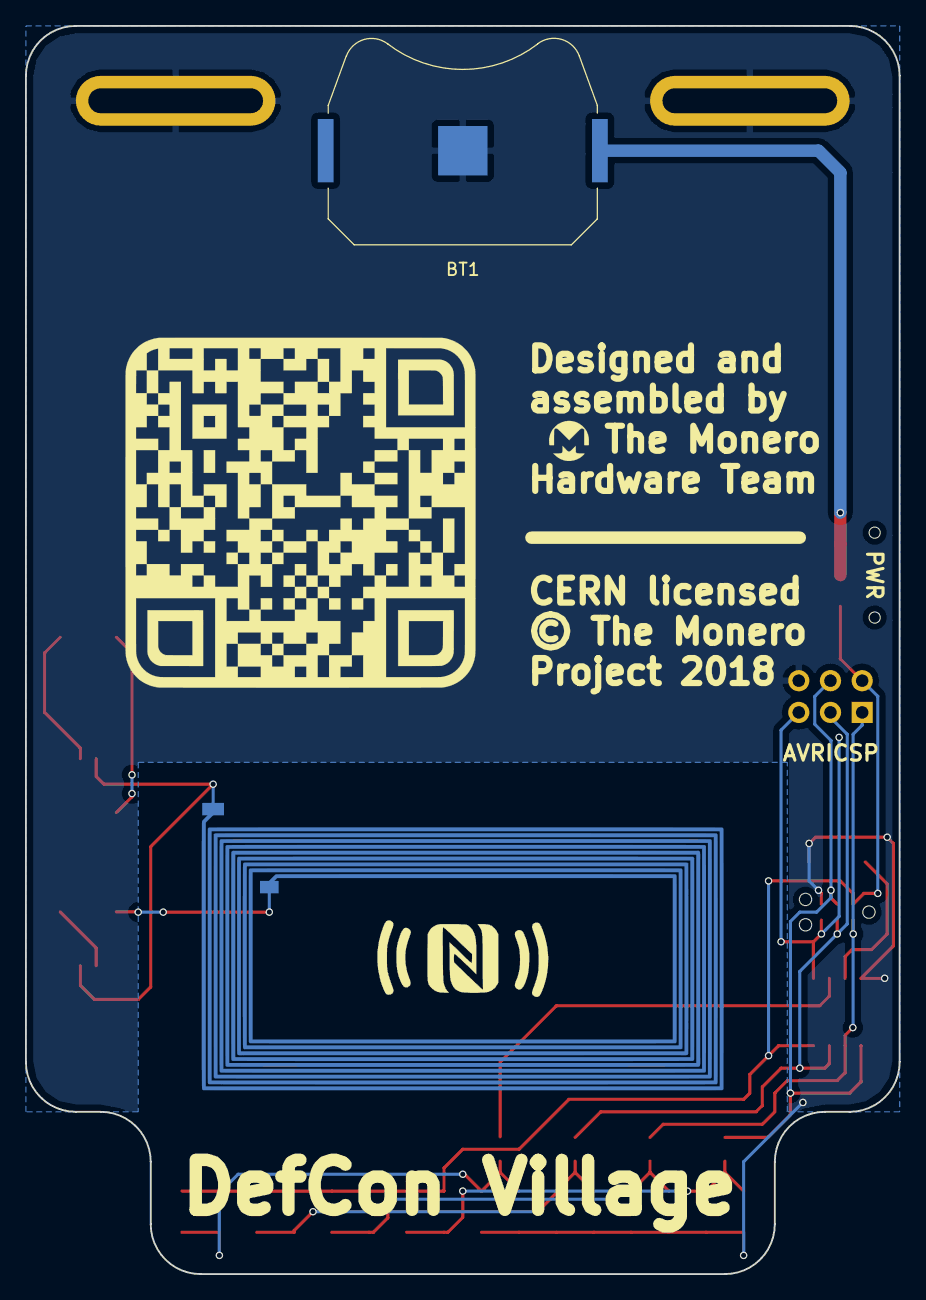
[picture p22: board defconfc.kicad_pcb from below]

Board: 2 copper layers, 70.0 x 100.0 mm, 39 parts (5 on the bottom side), 17 nets.

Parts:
AE1: Antenna_PCB; NFCAntennaloop
BT1: Battery_Cell; Keystone_3034_1x2032-Coincell
D1, D2, D3, D4, D5, D6, D7, D8, D9, D10, D11, D12, D13, D14, D15, D16: LED; LED_1206
FID1, FID2, FID3: Fiducial_Passermarke; Fiducial_1mm_Dia_2mm_Outer
G1: NFCRadiate; NFCGraphicsrear
G2: Kastelospecs; Kastelospecsqrcode
J1: Conn_02x03_Odd_Even; Tag-Connect_TC2030-IDC-NL
J2: Conn_02x03_Odd_Even; Pin_Header_Straight_2x03_Pitch2.54mm
L2: Graphbrand; Monerologokreis
LH1, LH2: Mounting-Lanyard; LanyardHole_16mm_Pad
R1, R3, R5, R7: 220; R_0805
SW1, SW2, SW3: SW_SPST; SW_SPST_PTS645
SW4: SW_SPDT; SW_SPDT_CK-JS102011SAQN
U1, U2: M24SR16-YMN6T/2; SOIC-8_3.9x4.9mm_Pitch1.27mm
U3: ATTINY13A-SSU; SOIC-8_3.9x4.9mm_Pitch1.27mm

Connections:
GND: BT1.2, D2.1, D4.1, D6.1, D8.1, D10.1, D12.1, D14.1, D16.1, J1.6, J2.6, LH1.1, LH2.1, SW3.2, U1.4, U2.4, U3.4
MISO: J1.1, J2.1, R3.2, U3.6
MOSI: J1.4, J2.4, R1.2, U3.5
unnamed: AE1.1, U1.2, U2.2
unnamed: AE1.2, SW1.1, SW2.1
unnamed: BT1.1, SW4.1, SW4.2
unnamed: D1.1, D2.2, D3.1, D4.2, R1.1
unnamed: D5.1, D6.2, D7.1, D8.2, R3.1
unnamed: D9.1, D10.2, D11.1, D12.2, R5.1
unnamed: D13.1, D14.2, D15.1, D16.2, R7.1
unnamed: SW1.2, U1.3
unnamed: SW2.2, U2.3
unnamed: SW3.1, U3.3
PB3: R7.2, U3.2
RST: J1.5, J2.5, U3.1
SCK: J1.3, J2.3, R5.2, U3.7
VCC: D1.2, D3.2, D5.2, D7.2, D9.2, D11.2, D13.2, D15.2, J1.2, J2.2, SW4.3, U3.8

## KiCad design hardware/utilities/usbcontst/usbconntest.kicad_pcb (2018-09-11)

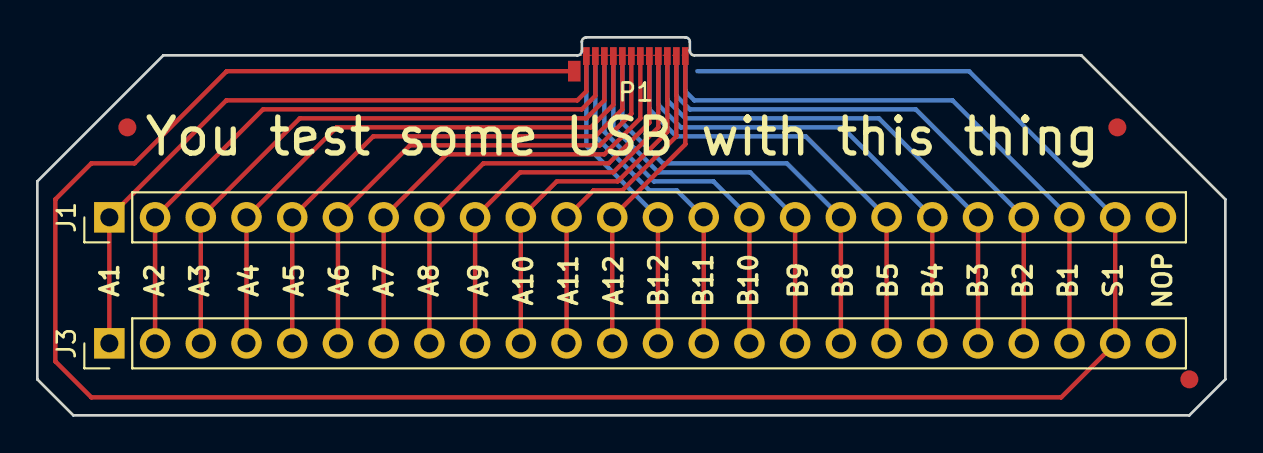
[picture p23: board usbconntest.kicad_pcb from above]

Board: 2 copper layers, 66.0 x 21.0 mm, 6 parts (0 on the bottom side), 23 nets.

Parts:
FID1, FID2, FID3: Dummy_FIDUCIAL_Passermarke_Type1_RevE_Date16Nov20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; Fiducial_1mm_Dia_2mm_Outer
J1, J3: CONN_01X24; Pin_Header_Straight_1x24_Pitch2.54mm
P1: USB_C_Plug; USB_C_Plug_Molex_105444

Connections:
/A1: J1.1, J3.1, P1.A1
/A2: J1.2, J3.2, P1.A2
/A3: J1.3, J3.3, P1.A3
/A4: J1.4, J3.4, P1.A4
/A5: J1.5, J3.5, P1.A5
/A6: J1.6, J3.6, P1.A6
/A7: J1.7, J3.7, P1.A7
/A8: J1.8, J3.8, P1.A8
/A9: J1.9, J3.9, P1.A9
/A10: J1.10, J3.10, P1.A10
/A11: J1.11, J3.11, P1.A11
/A12: J1.12, J3.12, P1.A12
/B1: J1.22, J3.22, P1.B1
/B2: J1.21, J3.21, P1.B2
/B3: J1.20, J3.20, P1.B3
/B4: J1.19, J3.19, P1.B4
/B5: J1.18, J3.18, P1.B5
/B8: J1.17, J3.17, P1.B8
/B9: J1.16, J3.16, P1.B9
/B10: J1.15, J3.15, P1.B10
/B11: J1.14, J3.14, P1.B11
/B12: J1.13, J3.13, P1.B12
/S1: J1.23, J3.23, P1.S1

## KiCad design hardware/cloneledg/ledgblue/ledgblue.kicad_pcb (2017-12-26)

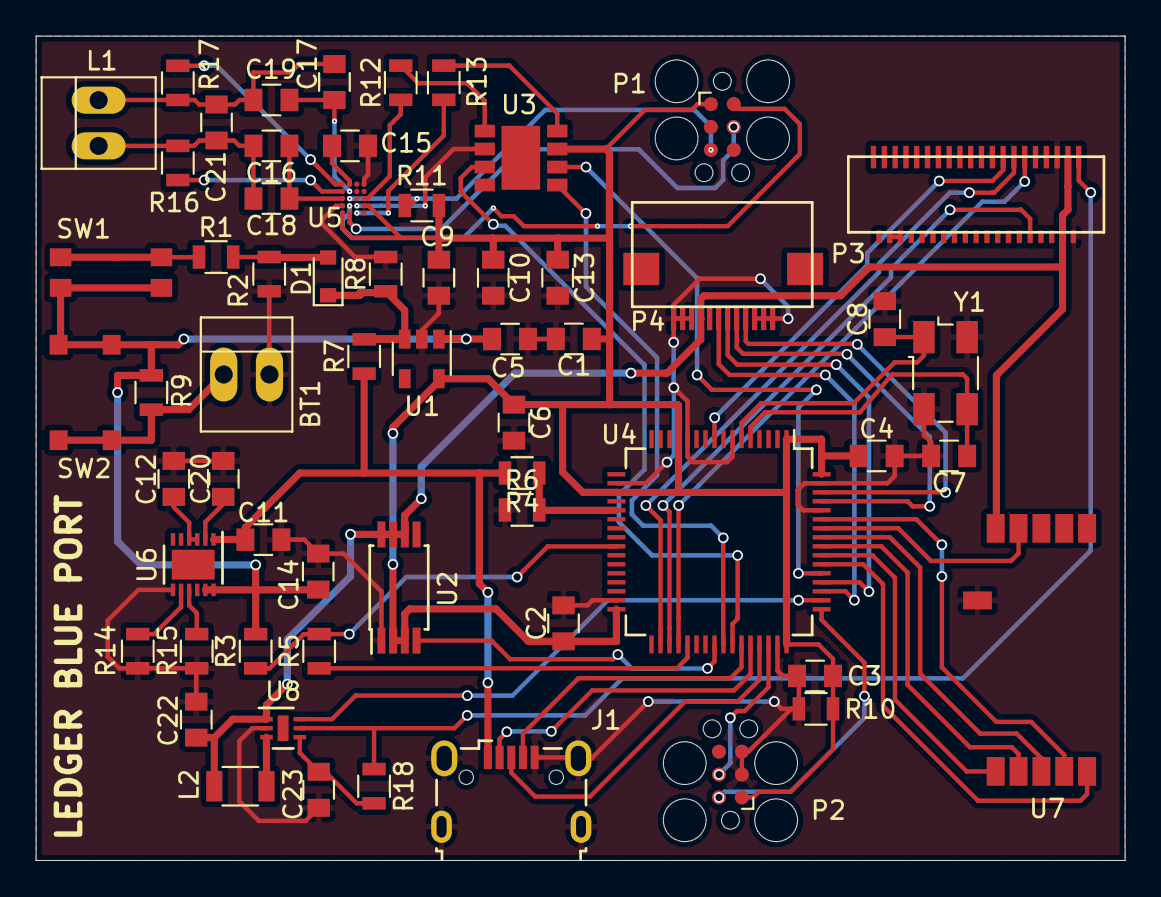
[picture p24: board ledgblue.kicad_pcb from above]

Board: 2 copper layers, 60.5 x 45.8 mm, 61 parts (0 on the bottom side), 59 nets.

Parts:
BT1: Battery; PINHEAD1-2
C1, C2, C3, C4, C9, C13: 100nF; C_0805
C5, C6, C22, C23: 1uF; C_0805
C7, C8: 20pF; C_0805
C10, C14: 4.7uF; C_0805
C11, C12, C20: 2.2uF; C_0805
C15: 15nF; C_0805
C16, C17: 27pF; C_0805
C18, C19: 180pF; C_0805
C21: 39pF; C_0805
D1: D_Schottky; D_0805
J1: USB_OTG; USB_Micro-B_Wuerth-629105150521
L1: Antenna; PINHEAD1-2
L2: 10uH; L_1206
P1, P2: DEBUG; Tag-Connect_TC2030-IDC-FP
P3: YL035MY2; hiroseFH23-39S
P4: YL035MY2_TS_WURTH; wurth687-112-149-022
R1, R2, R14: 10k; R_0805
R3, R4, R5, R6: 1.2k; R_0805
R7: 680k; R_0805
R8: 1M; R_0805
R9, R12, R13, R16, R17: 0; R_0805
R10, R11: 100k; R_0805
R15: 1k; R_0805
R18: 10; R_0805
SW1: WURTH 436353045816; wurth436353045816
SW2: SW-PB; multicompMCFTE-3C-V
U1: LD39020_3.0V; SOT-23-5
U2: STMPS2151TTR; TSSOP-8_4.4x3mm_Pitch0.65mm
U3: ST31G480
U4: STM32L476RCT6; LQFP-64_10x10mm_Pitch0.5mm
U5: AMS_AS3921; amsAS3921
U6: STNS01PUR; DFN-12-1EP_3x3mm_Pitch0.45mm
U7: SPBTLE-RF; STSPBTLE-RF
U8: STLA02PUR; DFN-6-1EP_2x2mm_Pitch0.5mm
Y1: 8 MHz; Crystal_SMD_Abracon_ABM3B-4pin_5.0x3.2mm

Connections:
+BATT: C5.1, C14.2, R3.2, R9.1, SW1.1, SW2.1, U1.1, U6.11, U6.12
AUX_PWR: C22.2, L2.2, P3.3, P3.4, P4.9, U2.6, U2.7, U2.8, U7.5, U8.1
AUX_PWR_enable: U2.4, U4.40
BC_ADC_EN: R5.1, U4.37
BC_ADC_IN: R3.1, R5.2, U4.25
BLE_CS: U4.59, U7.10
BLE_IRQ: U4.58, U7.4
BLE_MISO: U4.56, U7.8
BLE_MOSI: U4.57, U7.9
BLE_RST: U4.54, U7.11
BLE_SCK: U4.55, U7.7
Backlight_PWM: U4.50, U8.6
ButtonIT: D1.2, R1.2, R2.1
DISP_SCL: P3.13, U4.34
Disp_CS: P3.10, U4.35
Disp_RESET: P3.15, U4.9
Disp_SDA: P3.11, U4.36
LED_A: P3.1, R18.1, U8.5
MAIN_POWER: C1.1, C2.1, C3.1, C4.1, C6.1, C9.1, C10.1, C13.1, P1.1, P2.1, R10.2, R11.2, U1.5, U2.2, U2.3, U3.7, U4.1, U4.13, U4.19, U4.32, U4.48, U4.64, U5.A4, U5.D5
NRST: BT1.2, C1.2, C2.2, C3.2, C4.2, C5.2, C6.2, C7.2, C8.2, C9.2, C10.2, C11.2, C12.2, C13.2, C14.1, C15.2, C20.1, C22.1, C23.2, J1.5, J1.6, P2.3, P2.5, P3.2, P3.5, P3.34, P3.36, P4.1, P4.2, P4.3, P4.10, P4.11, P4.12, R2.2, R6.1, R8.2, R10.1, R14.2, R15.2, U1.2, U2.1, U3.2, U4.7, U4.12, U4.18, U4.31, U4.47, U4.60, U4.63, U5.A1, U5.B1, U5.B4, U5.D4, U6.7, U7.6, U8.2, Y1.2, Y1.4
unnamed: BT1.1, R9.2, SW2.2
unnamed: C7.1, U4.5, Y1.3
unnamed: C8.1, U4.6, Y1.1
unnamed: C12.1, U6.2
unnamed: C15.1, U5.C1
unnamed: C16.1, C18.1, U5.D3
unnamed: C16.2, C18.2, C21.1, L1.1, R16.1
unnamed: C17.1, C19.1, U5.C2
unnamed: C17.2, C19.2, C21.2, L1.2, R17.1
unnamed: C20.2, U6.3, U6.4
unnamed: C23.1, R18.2, U8.4
unnamed: D1.1, R7.2, R8.1, U1.3
unnamed: L2.1, U8.3
unnamed: P1.2, U5.C4
unnamed: P1.4, U5.C5
unnamed: P1.5, R11.1, U5.C3
unnamed: R1.1, SW1.2
unnamed: R12.1, U5.A3
unnamed: R12.2, U3.1
unnamed: R13.1, U5.B5
unnamed: R13.2, U3.8
unnamed: R14.1, U6.8
unnamed: R15.1, U6.9
unnamed: R16.2, U5.D2
unnamed: R17.2, U5.D1
SE_CLK: U3.5, U4.41
SE_IO: U3.3, U4.42
SE_RST: U3.6, U4.53
SWCLK: P2.2, U4.49
SWIO: P2.4, U4.46
TS_CE: P4.7, U4.51
TS_IRQ: P4.6, U4.52
TS_SCL: P4.5, U4.61
TS_SDA: P4.4, U4.62
USBDM: J1.2, U4.44
USBDP: J1.3, U4.45
USBID: J1.4, U4.43
VBUS: C11.1, J1.1, R4.2, R7.1, U6.1
VBUS_PRE: R4.1, R6.2, U4.21

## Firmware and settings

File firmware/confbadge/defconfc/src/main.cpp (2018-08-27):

// https://nevcx.wordpress.com/2013/08/18/programming-an-attiny13a-using-arduinoisp/

#include "main.h"

byte aniframe;
byte animidxnum = 0;
const byte animidxmax = 8;
unsigned long prevmillisec = 0;
unsigned long currmillisec = 0;
const long delayfade1 = 1500;
const long delayfade2 = 2500;
const int repeatfade2 = 16000;

const byte lengthfade1 = 19;
const byte cylonscan[lengthfade1] PROGMEM = {
  0x80, 0xC0, 0x60, 0x30, 0x18, 0x0C, 0x06, 0x03, 0x01, 0x00,
  0x01, 0x03, 0x06, 0x0C, 0x18, 0x30, 0x60, 0xC0, 0x80
};

const byte lengthfade2 = 7;
const byte alienscan1[lengthfade2] PROGMEM = {
  0x81, 0x42, 0x24, 0x18, 0x24, 0x42, 0x81
};

const byte lengthfade3 = 9;
const byte alienscan2[lengthfade3] PROGMEM = {
  0x81, 0x42, 0x24, 0x18, 0x18, 0x3C, 0x7E, 0xFF, 0xFF
};

const byte lengthfade4 = 15;
const byte bossflash[lengthfade4] PROGMEM = {
  0xF0, 0x00, 0xF0, 0x00, 0xF0, 0x00, 0xF0, 0x00,
  0x0F, 0x00, 0x0F, 0x00, 0x0F, 0x00, 0x0F
};

const byte lengthfade5 = 2;
const byte allflash[lengthfade5] PROGMEM = {
  0b11111111, 0x00
};

const byte leftflash[lengthfade5] PROGMEM = {
  0b11110000, 0x00
  //0b00110011
  //looks like
  //0b11110000
};

const byte rightflash[lengthfade5] PROGMEM = {
  0b00001111, 0x00
  //0b11001100
  //looks like
  //0b00001111
};

byte binctr = 0;

void setup() {
  // Voodoo AVR registers
  ADCSRA &= ~(1 << ADEN);
  PORTB |= (1 << PB4);
  DDRB &= ~(1 << PB4);
}

// Sample SPST on GPIO PB4 at end of each animation loop
void chkbutstate() {
  if (!(PINB & (1 << PB4))) {
    aniframe = 0;
    animidxnum++;

    if (animidxnum > animidxmax) {
      animidxnum = 0;  // Reset to first anim
    }

    {
      blinkled();  // Serves as user feedback
      blinkled();  // to indicate that an anim
      blinkled();  // has iterated via SPST
    }

    prevmillisec = currmillisec;  // Reset timer
  }
}

// Arduino compatible loop block
void loop() {
  currmillisec = millis();  // Set timer
  chkbutstate();            // Sample SPST

  switch (animidxnum) {
    case 0:
      animate(
        delayfade2,
        lengthfade1,
        repeatfade2,
        cylonscan
      );
      break;

    case 1:
      animate(
        0,
        lengthfade1,
        repeatfade2/2,
        cylonscan
      );
      break;

    case 2:
      animate(
        delayfade1,
        lengthfade2,
        repeatfade2,
        alienscan1
      );
      break;

    case 3:
      animate(
        1500,
        lengthfade3,
        16000,
        alienscan2
      );
      break;

    case 4:
      animate(
        0,
        lengthfade4,
        8000,
        bossflash
      );
      break;

    case 5:
      animate(
        0,
        lengthfade5,
        16000,
        allflash
      );
      break;

    case 6:
      animate(
        0,
        lengthfade5,
        16000,
        leftflash
      );
      break;

    case 7:
      animate(
        0,
        lengthfade5,
        16000,
        rightflash
      );
      break;

    case 8:
      showframe(16000);
      aniframe++;
      break;

    default:
      alledsoff();
      break;
  }
}

void animate(int anidelay, byte arraylength, int arrayrepeat, const byte* array) {
  if (currmillisec - prevmillisec >= (unsigned long)anidelay) {
    for (byte niter = 0; niter < arraylength; niter++) {
      prevmillisec = currmillisec;
      aniframe = pgm_read_byte_near(array + niter);
      showframe(arrayrepeat);
    }
    alledsoff();
  }
}

void showframe(int framerep) {
  for (int niter = 0; niter < framerep; niter++) {
    alledsoff();
    PORTB |= (0x0F & aniframe);
    DDRB |= (0x0F & aniframe);

    alledsoff();
    DDRB |= (0x0F & (aniframe >> 4));
  }
}

// Completely dim all LEDs in array
void alledsoff() {
  DDRB &= ~(0x0F);
  PORTB &= ~(0x0F);
}

// Illuminate a LED in array
void showprog(byte progidx) {
  if (progidx < 16) {
    alledsoff();
    PORTB |= (0x0F & progidx);
    DDRB |= (0x0F & progidx);
  }
  else {
    alledsoff();
    DDRB |= (0x0F & (progidx >> 4));
  }
}

// Simply blink a certain lamp in LED array according to
// the current animation index, to indicate user feedback
void blinkled() {
  showprog(1 << animidxnum);
  delay(200);
  alledsoff();
  delay(100);
}

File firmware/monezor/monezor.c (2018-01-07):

/*
 * This file is part of the TREZOR project, https://trezor.io/
 *
 * Copyright (C) 2014 Pavol Rusnak <stick@satoshilabs.com>
 *
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
 * You should have received a copy of the GNU Lesser General Public License
 * along with this library.  If not, see <http://www.gnu.org/licenses/>.
 */

#include <string.h>
#include <libopencm3/usb/usbd.h>
#include <libopencm3/usb/hid.h>
#include <libopencm3/stm32/gpio.h>
#include "bitmaps.h"
#include "display.h"
#include "setup.h"
#include "usb.h"
#include "util.h"




int main(void)
{
	setup();
	oledInit();
	usbInit();

	oledClear();
	oledDrawBitmap(42, 11, &bmp_logo64);
				
	while(1) {
		
		usb_poll();
		oledDrawBitmap(42, 11, &bmp_logo64);
		oledRefresh();
		
		if (!gpio_get(GPIOC, GPIO5)){
			oledDrawBitmap(10, 11, &bmp_logo64);
			oledSwipeRight();
			oledDrawBitmap(70, 11, &bmp_logo64);
			oledSwipeLeft();
		}
		
		if (!gpio_get(GPIOC, GPIO2)){
			oledInvert(0,0,128,64);
			delay(1000000);
			oledRefresh();
		}
		oledClear();
	
	}

	return 0;
}

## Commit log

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2017-11-17 Created a Julian Candy manufacturing panel for single board design.
    [monezor-B.Cu.gbr, monezor-B.Mask.gbr, monezor-B.Paste.gbr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]
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2017-11-20 Made the board compatible with OSHPARK requirements
    Solder mask, silkscreen and board outline gerbers were added. The layer files have been renamed to be compatible with OSHPARK.
    [ziftosma_d2.GBL, ziftosma_d2.GKO, ziftosma_d2.GTL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]
2017-11-20 Flexible bluetooth antenna
    Flextenna BT (flexible bluetooth antenna) based on Kapton substrate, optimized for a center frequency of 2.45 GHz.
    [flextenna_bt_kapton5um.GKO, flextenna_bt_kapton5um.GTL]
2017-11-20 Added two dimensional size information to user drawings layer.
    [monezor.kicad_pcb]
2017-11-20 Remaked panelization, added fiducials, generated new manufacturing data
    [monezor-B.Cu.gbr, monezor-B.Mask.gbr, monezor-B.Paste.gbr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]
2017-12-05 Port of the Ledger Blue
    Port of the Ledger Blue. Secure elements not connected yet.
    [ledgblue.kicad_pcb, ledgblue.sch, p1_hiroseFH23-39S-0.3SHW.dxf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]
2017-12-05 Cleaning up of file names
    Cleaned up the readme.md and filenames a bit.
    [ziftosma.GBL, ziftosma.GKO, ziftosma.GTL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]
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2017-12-09 Layout has been compacted
    The layout has been shrunk a bit. A pin header is used as placeholder for the antenna. NFC chip still not connected.
    [ledgblue.kicad_pcb, ledgblue.sch]
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2017-12-19 Added a generated bill of materials for an imminent parts order.
    [ledgblue-bill.csv]
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2018-01-07 Resaved from ODS format to FODS (flat file) for SCM text base benefits.
    [ledgour_bom.ods]
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2018-02-08 Corrected resolution of Breakneck version numbers and improved readme.
    [breakneck.kicad_pcb, breakneck.sch]
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2018-02-10 Corrected and improved Monero logo, display connector, and MCU libraries.
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2018-02-10 Appended the Monero logo to all work sheet title blocks by default.
    [breakneck.sch]
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2018-02-12 Corrected flawed ATECC608A symbol, introduced ATAES132A circuit, and made improvements such as adding crystal test points and a AuthO LED.
    [breakneck.sch]
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2018-02-15 Corrected flawed OLED_D(0|1) anchor labels to logical display connections.
    [breakneck.sch]
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2018-02-17 Replaced a DNP zero ohm resistor with a more appropriate solder jumper.
    [breakneck.sch]
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2018-02-26 Replaced routed USB-C with drill slotted, and added a footprint archive.
    [breakneck.kicad_pcb, breakneck.sch]
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2018-02-28 Added local copies of 3D shapes, made footprint location consistent to native KiCad, and changed holes.
    [breakneck.kicad_pcb]
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2018-03-03 Corrected scaling and rotation of shapes, and connected ground paths.
    [breakneck.kicad_pcb]
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2018-03-04 Moved C3 from under SW1, removed redundant SW traces, and aligned vias.
    [breakneck.kicad_pcb]
2018-03-04 Connected 32KHz crystal, RTC, and tamper pins for timing attacks, and added a solder bridge jumper to support a suitable ground bridge when not in use (unfortunately causing massive net and schematic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
    [breakneck.kicad_pcb, breakneck.sch]
2018-03-04 Resolved false no connects in internally connected switches, by hacking.
    [breakneck.kicad_pcb]
2018-03-04 Resolved unconnected bootloader and reset pins, and improved 3V3 and GND.
    [breakneck.kicad_pcb]
2018-03-04 Replaced copper masked logo in the least problematic place found.
    [breakneck.kicad_pcb]
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2018-03-06 Routed USB data bus, routed secondary SPI bus (pins 33-36), and stripped hand tooled jumpers and pads of solder in technical layer.
    [breakneck.kicad_pcb]
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2018-03-07 Replaced SOT89 sized MCP1703 regulator with an equivalent SOT23 package.
    [breakneck.csv, breakneck.kicad_pcb, breakneck.sch]
2018-03-07 Eliminated all ground lead no connect errors from the design rule check.
    [breakneck.kicad_pcb]
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2018-03-08 Corrected SOT-23 3D shape absolute path, removing step and adding wings.
    [breakneck.kicad_pcb]
2018-03-08 Added a event bus for polling external SPI slave mode data connections.
    [breakneck.csv, breakneck.kicad_pcb, breakneck.sch]
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2018-03-10 Corrected nonportable library, module, and model descriptors.
    [breakneck.kicad_pcb, breakneck.sch]
2018-03-11 Corrected several errors in diode polarity, power conflicts (still not perfect), and solder jumper inputs (GS2), as well as cleaned up unused and redundant traces and silkscreened documentation on bo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
    [breakneck.kicad_pcb, breakneck.sch]
2018-03-11 Improved reset circuit by replacing with low profile angled hardware.
    [breakneck.kicad_pcb, breakneck.sch]
2018-03-11 Corrected some no connects and assigned angled hardware to glitch point.
    [breakneck.kicad_pcb, breakneck.sch]
2018-03-11 Cut a lift slot into the board edge for purposes of a future enclosure.
    [breakneck.kicad_pcb]
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2018-03-17 Updated, corrected, and reformatted bill of materials (including ALS.)
    [breakneck.csv]
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2018-03-18 Integrated missing battery clip and provisional tap detector circuit.
    [breakneck.csv, breakneck.kicad_pcb, breakneck.sch]
2018-03-18 Included missing recent diode addition to battery circuit.
    [breakneck.csv]
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2018-03-19 Implemented workaround pulling down USB-C CC lines to indicate power sink.
    [breakneck.kicad_pcb, breakneck.sch]
2018-03-20 Replaced hand solder DS1 with FPC connector, supporting archives only.
    [breakneck.kicad_pcb, breakneck.sch]
2018-03-25 Replaced Hirose FPC (30-pin ,5mm pitch) with correct Eastrising equivalent.
    [breakneck.kicad_pcb]
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2018-03-27 Completed and corrected models, removed easteregg, and included datasheets.
    A number of funky hacks allow for 3D model rendering to look good, by
    specifying similar shaped packages for lacking models such as LGA-2mm
    and 6-pin LED chips. I hacked the rendering even more to represent a
    battery clip that's not the one in use at all, which could be misleading.
    [breakneck.kicad_pcb, breakneck.sch]
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2018-10-09 Do a live on site conference badge super commital #HCPP18, integrating hardware design sources for the conference badge.
    [hcppnfc.kicad_pcb, hcppnfc.sch]
2018-10-25 Corrected USB-C slots, 2u2 notation, and C0G requirement for touch sensing.
    [breakneck.sch]
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2018-10-26 Annotated missing fiducial symbol fields in number ordered fashion.
    [breakneck.sch]
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2018-10-26 Completed (and corrected pin configuration of) QFN28 packaged CP2102N.
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2018-10-26 Implemented UART bridging, USB bus power circuit to 3V3, LED and ESD.
    [breakneck.sch]
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2018-10-29 Linked OLED SPI lines into the ADC port, for better or for worse.
    [breakneck.sch]
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2018-10-30 Took a mini break and implemented fun Badgebus, SAO, and battery backup.
    [breakneck.sch]
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2018-10-30 Corrected power filtering for phase locked loop (main CPU 48MHz clock.)
    [breakneck.sch]
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2018-10-30 Included and reworked external crystal resonator circuit.
    [breakneck.sch]
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2018-10-30 Made power decoupling and other improvements as well as corrections.
    [breakneck.sch]
2018-11-03 Commented that we may benefit from a external timer in the future.
    [breakneck.sch]
2018-11-03 Implemented security enhancement as per in 4,2 ECC508 Interface Pins, specified in document CEC1702 ROM Description Addendum, Table 4-2 CEC1702 ECC508 Interface Pins.
    [breakneck.sch]
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2018-11-06 Added testpoints and reduced problems found by modified ERC scanner.
    [breakneck.sch]
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2018-11-06 Corrected pin header SAO footprints and added missing badgebus.
    [breakneck.sch]
2018-11-06 Added missing WFBGA footprint and shape models for CEC1702 layout.
2018-11-06 Shrunk test points, populated footprint index, and corrected SC-70.
    [breakneck.sch]
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2018-11-07 Corrected a last time towards staging display connectors before moving.
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2018-11-08 Corrected missing, flawed, and other footprint package changes.
    [breakneck-bill.csv, breakneck.csv, breakneck.sch]
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2018-11-08 Added JST PH connector symbol to introduce early support for 3V7 power.
    [breakneck-bill.csv, breakneck.sch]
2018-11-09 Corrected flawed symbol named with slash characters to remove them.
    [breakneck.sch]
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2018-11-10 Added missing logo text symbol and corrected fiducial layer.
    [breakneck.sch]
2018-11-10 Changed JTAG footprint, improved SAO legend, and corrected models.
    [breakneck.kicad_pcb, breakneck.sch]
2018-11-10 Updated schematic with recent corrections, additions, and improvements.
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2018-11-13 Completed decoupling capacitors, reset, switches, and improved crystal.
    [breakneck.kicad_pcb]
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2018-12-05 Corrected accidentally moved height dimension marker in user drawings.
    [breakneck.kicad_pcb]
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2018-12-16 Included a first draft of a suitable PLA or ABS enclosure for FDM.
    [bneckfdmpla.fcstd]
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2018-12-24 Minimised clearance, added grip cutout, and adjusted connectors and fillets.
    [bneckfdmpla.fcstd]
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2018-12-31 Corrected and improved design to beta grade quality pending release; Added second battery, added Monero graphics, removed third party logos, corrected inverter circuit, corrected weak pin fastener, c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
    [35C3XMR-bill.csv, 35C3XMR-bot.csv, 35C3XMR-top.csv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]
2018-12-31 Documented unconnected parts to reduce unintentional short circuits.
    [35C3XMR-bill.csv, 35C3XMR-top.csv, 35C3XMR.kicad_pcb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]
2018-12-31 Corrected broken link to raster circuit rendering.
2018-12-31 Flushed current changes to accommodate results of recent assembly tests; Introduced plastics engineering resources, made fiducial marks SMT for placing, merged SMT attribute to panel design according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
    [breakneck.kicad_pcb, breakneckimprt-pnp.csv, breakpanel.kicad_pcb]
2018-12-31 Archived STM32 based Monezor designs to accommodate CEC1702 migration; The archives are found in the revstm branch of the Monezor codebase.
    [monezor-B.Cu.gbr, monezor-B.Mask.gbr, monezor-B.Paste.gbr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]
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2019-01-03 Completed USBC debugging structures, including removal of unused contacts, symbol adaptation, introduction of solderbridges, test point connections, and complete segregation of inner row USBC connect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
    [breakneck.kicad_pcb, breakneck.sch, breakpanel.kicad_pcb]
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2019-01-05 Corrected cut and paste minor inconsistency in image text.
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2019-01-07 Removed manufacturing placement archive to correct for redundancy.
    [breakneckimprt-pnp.csv]
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2019-01-07 Included missing revision control filter logic.
2019-01-07 Included filter logic to avoid tracking local support files.
2019-01-07 Corrected slightly flawed field delimiters to allow parsing.
    [breakneck-bill.csv]
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2019-01-13 Corrected undersized panel tab mouse bite NPTH drills.
2019-01-13 Bumped revision identifiers and legal text pending new year of the pig.
    [breakneck.kicad_pcb, breakneck.sch, breakpanel.kicad_pcb]
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2019-01-14 Corrected fiducial placement on wrong side of board panel.
    [breakpanel.kicad_pcb]
2019-01-14 Corrected last remaining bottom fiducials to top and removed footprint.
    [breakneck.sch]
2019-01-14 Corrected switching as VCI_IN0 is a wakeup or interrupt on active low.
    [breakneck.kicad_pcb, breakneck.sch]
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2019-01-17 Corrected incompatible SE (608A) timing in ROM assistance.
    This follows advice taken from Microchip case 00347747, warning against
    replacing the CEC1702 ROM addendum specification of ATECC508A with the
    more capable ATECC608A SE.
    [breakneck-bill.csv, breakneck.kicad_pcb, breakneck.sch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]
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2019-01-18 Removed partless footprint module identifiers.
    The removed identifiers include mount holes, logo graphics,
    solder jumpers, tag connects, and fiducial marks.
    [breakneck-bill.csv]
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2019-01-19 Adjusted clearance to accommodate detector switch height.
    [bneckfdmpla.fcstd]
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2019-02-10 Reengineered enclosure top and unfortunately replace SVG with closed format.
2019-02-11 Corrected corner radius sizes and added switch facing retainers.
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2019-02-25 Solved USB snap through wall problem by adding a bezel, and angle reduced board guides to allow a custom board fit.
    [bneckfdmpla.fcstd]
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2019-05-17 Added a button cover model to replace current acrylic cutting.
    [bneckbuttons.fcstd]
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2019-12-05 Added a second 0,2mm layer to text areas to reinforce clarity.
    [bneckfdmpla.fcstd]
2019-12-09 Redesigned main brand text to include contrast outline, at great bother.
    [bneckfdmpla.fcstd]
2019-12-09 Added half layer depth to textual light colours for hole cover in mesh.
    [bneckfdmpla.fcstd]
2019-12-12 Removed dark coloured text backing and added a layer to text outlines.
    [bneckfdmpla.fcstd]
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2019-12-14 Corrected resin symbol surface replaced at top of floor thickness.
    [bneckfdmpla.fcstd]
2019-12-14 Corrected syntax errors, presumably left over from post processing.
    [breakneckimprt-bot.csv]
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2019-12-14 Added missing layout symbols for complete automated placement.
    [breakneckimprt-top.csv]
2019-12-14 Corrected flawed (wrong edge perspective) origin for placement offsets.
    [breakneckimprt-bot.csv]
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2019-12-20 Reduced height from 16mm to 15mm and corrected flawed constraints.
    [bneckfdmpla.fcstd]
2019-12-20 Corrected flawed sizes of hex nut housings, for FDM production only.
    [bneckfdmpla.fcstd]
2019-12-21 Corrected flawed calculation of hexnut diameter to use the spreadsheet.
    [bneckfdmpla.fcstd]
2019-12-23 Tried to finalise hexnut size correction for FDM mesh conversion.
    [bneckfdmpla.fcstd]
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2020-01-21 Increased floor space for more accessory payload and corrected USB.
    [bneckfdmpla.fcstd]
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2020-01-21 Corrected wall thickness of upper connector pocket for FDM process.
    [bneckfdmpla.fcstd]
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2020-01-28 Corrected width of male type-C USB pocket (slider) through front wall.
    [bneckfdmpla.fcstd]

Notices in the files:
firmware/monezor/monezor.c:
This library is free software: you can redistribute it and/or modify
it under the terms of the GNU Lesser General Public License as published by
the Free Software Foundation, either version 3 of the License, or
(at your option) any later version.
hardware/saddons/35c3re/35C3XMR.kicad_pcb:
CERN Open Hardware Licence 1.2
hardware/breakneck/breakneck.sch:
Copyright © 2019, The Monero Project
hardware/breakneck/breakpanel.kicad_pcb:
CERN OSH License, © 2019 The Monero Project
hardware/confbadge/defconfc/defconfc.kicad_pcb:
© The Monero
